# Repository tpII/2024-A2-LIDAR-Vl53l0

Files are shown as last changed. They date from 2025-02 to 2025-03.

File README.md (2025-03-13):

<!-- Titulo del proyecto -->

# A2-LIDAR-VL53L0X - CYCLOPS

<!-- Logo -->
<div align="center">
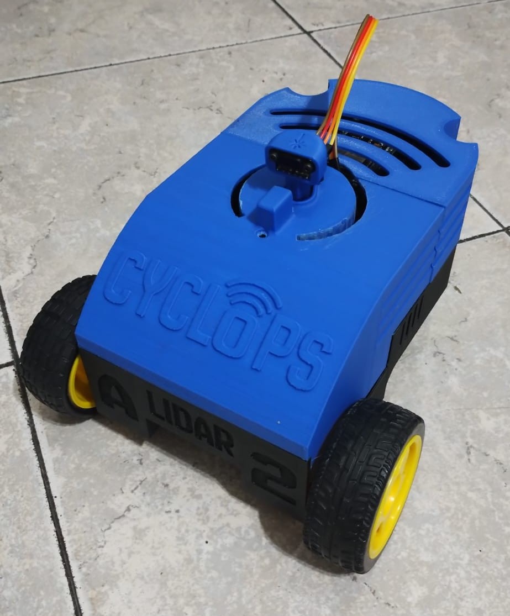
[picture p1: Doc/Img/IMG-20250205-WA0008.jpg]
  
</div>

<!-- Descripción del proyecto -->

Originalme **A2-LIDAR-VL53L0X, apodado Cyclops (en honor al héroe de Marvel)**, es un robot vehículo de 3 ruedas, de las cuales dos son motorizadas por motores DC, mientras que la tercera es una rueda loca que permite maniobras ágiles de desplazamiento.

El proyecto se destaca por el uso de un sensor **LiDAR VL53L0X montado sobre un servomotor de giro continuo**, lo que le permite al robot **detectar obstáculos** en su entorno en un radio de **300 grados**. La **MCU ESP32** gestiona todo el funcionamiento, comunicándose con el backend mediante HTTP y MQTT para recibir instrucciones y enviar datos como el nivel de batería, información del sistema y detalles de los obstáculos detectados, respectivamente.

El **backend**, desarrollado en **Maven con SpringBoot junto al broker Mosquitto**, almacena los datos para que puedan ser consultados tanto por el frontend como por el MCU. La base de datos utilizada es **MongoDB**.

El **frontend** está implementado con **Angular 18**, ofreciendo una **interfaz web** que permite **controlar el robot** mediante una serie de botones y con un mando conectado, además de **visualizar información** como el nivel de batería, mensajes de estado y un **mapa interactivo** que muestra los obstáculos detectados como **puntos en coordenadas <distancia, ángulo>.**

El objetivo principal de este proyecto fue desarrollar un **robot vehículo capaz de mapear su entorno y controlarlo** mediante una aplicación web de forma intuitiva y eficiente.

<details>
  <summary><i>:memo: Características del proyecto</i></summary>
  <ol>
    <li><b>Mapeo del Entorno<b></li>
    <p>Se puede decir que es la base del proyecto. Se realiza mediante la combinacion del sensor LiDAR VL53L0X que mide distancia, y un servomotor de giro continuo. Que mediante la logica adeacuada, scanea el entorno, obteniendo el par<distancia,angulo>. Que posteriormente se grafica en un mapa.</p>
    <li>Access Point</li>
    <p>El ESP32 actúa como punto de acceso (AP) para la conexión. De este modo la pc donde se ejectute el backend debe conectarse al la red del ESP32.</p>
    <li>Desarrollo Modular</li>
    <p>El programa está diseñado de manera modular, con componentes separados por funcionalidad, facilitando el mantenimiento y la extensión del proyecto.</p>
    <li>Replicabilidad</li>
    <p>El proyecto está documentado lo suficiente como para permitir replicar el control de un robot similar utilizando el hardware indicado.</p>
    <li>Extensibilidad</li>
    <p>Es posible ampliar el sistema para añadir mejoras de rendimiento o nuevas funcionalidades.</p>
  </ol>
    <li>Base educativa</li>
    <p>El proyecto es ideal para aprender acerca de programación de microcontroladores, conexiones hardware, utilizacion de sensores, integracion de Frontend<->Backend<->Hardware,sistemas concurrentes y de tiempo real, testeo y optimizacion de procesos.</p> </ol>
</details>

<details> 
  <summary><i>:satellite: Tecnologías utilizadas</i></summary>
  <ol> 
    <li>Aplicación web</li>
    <ul> 
      <li>Angular 18: framework frontend utilizado para la construcción de la interfaz de usuario, con un enfoque en componentes independientes y organización modular.</li>
      <li>Angular Material: utilizado para el diseño de la interfaz, proporcionando componentes estilizados y responsivos para una experiencia de usuario consistente.</li>
      <li>HTML, CSS y TypeScript: fundamentales para la estructura, estilo y lógica de la aplicación web, aprovechando las capacidades tipadas de TypeScript para un desarrollo más robusto.</li>
    </ul> 
    <li>Backend</li>
    <ul>
      <li>Java (Spring Boot): framework utilizado para construir el servidor backend, gestionando las solicitudes HTTP y la lógica de negocio.</li>
      <li>Maven: herramienta de gestión de dependencias y construcción del proyecto backend, asegurando un ciclo de desarrollo eficiente.</li>
      <li>MongoDB: base de datos NoSQL utilizada para almacenar la información persistente de la aplicación, con un enfoque en flexibilidad y escalabilidad.</li>
    </ul>
    <li>Comunicación en tiempo real</li>
    <ul>
      <li>Mosquitto Broker (MQTT): utilizado para la comunicación en tiempo real entre la aplicación web y el ESP32, permitiendo la transmisión de datos de forma eficiente y ligera.</li>
    </ul> 
    <li>ESP32</li>
    <ul>
      <li>Modo Soft AP: configurado como punto de acceso para permitir la conexión directa de dispositivos al ESP32.</li>
      <li>Programación en C: se utilizó para implementar la lógica de control del ESP32, incluyendo el manejo de sensores, motores y comunicación MQTT.</li>
      <li>PlatformIO: entorno de desarrollo integrado en Visual Studio Code para la programación y gestión del firmware del ESP32.</li>
      <li>DC Motors: utilizados para el movimiento del dispositivo, controlados mediante PWM para un desplazamiento preciso.</li>
      <li>Servo: utilizado para movimientos angulares específicos, controlado también mediante PWM.</li>
      <li>Sensores I2C: dos sensores conectados al ESP32 mediante el protocolo I2C para la recopilación de datos en tiempo real.</li>
    </ul>
  </ol>
</details>

<!-- Tabla de contenidos -->
<h1 id="table-of-contents">:book: Tabla de contenidos</h1>
<details open="open">
  <summary>Tabla de contenidos</summary>
  <ol>
    <li><a href="#prerequisites-software">➤ Prerequisitos-Software</a></li>
    <li><a href="#installation-esp32">➤ Instalación y Configuración del ESP32</a></li>
    <li><a href="#installation-mosquitto-broker">➤ Instalación y Configuración del Broker MQTT</a></li>
    <li><a href="#installation-backend">➤ Instalación y Configuración del Backend</a></li>
    <li><a href="#installation-mongodb">➤ Instalación y Configuración de MongoDB</a></li>
    <li><a href="#installation-frontend">➤ Instalación y Configuración del Frontend<</a></li>
    <li><a href="#execution-steps">➤ Pasos para la Ejecución del Proyecto</a></li>
    <li><a href="#video">➤ Video demostrativo</a></li>
    <li><a href="#bitacora">➤ Bitácora</a></li>
    <li><a href="#authors">➤ Autores</a></li>
    <li><a href="#coordinador">➤ Coordinador</a></li>
  </ol>
</details>

<!-- Prerequisitos SOFTWARE -->
<h1 id="prerequisites-software">🛠️ Prerequisitos-Software</h1>
<details>
  <summary>Prerequisitos-Software</summary>
  <p>El proyecto requiere la instalación de los siguientes componentes de software:</p>
  <ul>
    <li>
      <b>Visual Studio Code:</b> Editor de código necesario para el desarrollo tanto del frontend y backend, como del firmware para el ESP32.
    </li>
    <li>
      <b>PlatformIO:</b> Extensión de Visual Studio Code utilizada para compilar y cargar el firmware en el ESP32.
    </li>
    <li>
      <b>Java:</b> Requerido para ejecutar el backend en Spring Boot.
    </li>
    <li>
      <b>Maven:</b> Herramienta de gestión de dependencias y construcción para el backend en Spring Boot.
    </li>
    <li>
      <b>Node.js:</b> Necesario para Angular, incluyendo el uso de npm para la instalación de dependencias.
    </li>
    <li>
      <b>MongoDB:</b> Base de datos NoSQL utilizada para el almacenamiento de datos de la aplicación.
    </li>
    <li>
      <b>Broker Mosquitto:</b> Servidor MQTT utilizado para la comunicación en tiempo real con el ESP32.
    </li>
  </ul>
</details>

---

<!-- Prerequisitos ESP32 -->
<h1 id="installation-esp32">🛠️ Instalación y Configuración del ESP32</h1>
<details>
  <summary>Instalación y Configuración del ESP32</summary>
  <ol>
    <li>Abre <b>Visual Studio Code</b> y navega a la carpeta del proyecto: <code>2024-A2-LIDAR-VL53L0X</code>.</li>
    <li>Posiciónate en la carpeta <code>Microcontroller</code> (donde se encuentra el código en C).</li>
    <li>Conecta el ESP32 a un puerto USB de la computadora.</li>
    <li>Abrir <b>platformion.ini</b> y modificar <b>upload_port</b> con el numero de puerto al que se conecto el ESP32.</li>
    <li>Desde el menú inferior de <b>PlatformIO</b>, presiona el botón de subida de programa para compilar y cargar el firmware al ESP32.</li>
    <li>O en la consola, ejecutar <b>pio run -t upload<b></li>
  </ol>
  <p>Tras estos pasos, el ESP32 estará configurado y listo para ejecutar las instrucciones del proyecto.</p>
</details>

---

<!-- Prerequisitos BROKER MQTT-->
<h1 id="installation-mosquitto-broker">🕸️ Instalación y Configuración del Broker MQTT</h1>
<details>
  <summary>Instalación y Configuración del Broker Mosquitto</summary>
  <ol>
    <li>Descarga el instalador de Mosquitto MQTT Broker desde el sitio oficial de Eclipse Mosquitto: <a href="https://mosquitto.org/download/">https://mosquitto.org/download/</a>.</li>
    <li>Ejecuta el instalador y sigue las instrucciones para completar la instalación.</li>
    <li>Dirígete a la carpeta de instalación. Por defecto, se encuentra en:
      <pre><code>C:\Program Files\mosquitto</code></pre>
    </li>
    <li>Configura el Broker editando el archivo <code>mosquitto.conf</code> con un editor de texto (ej. Notepad++ o Visual Studio Code). Añade las siguientes líneas para permitir conexiones anónimas y habilitar la salida de eventos por consola:
      <pre><code>
listener 1883
allow_anonymous true
log_type all
connection_messages true
log_timestamp true
      </code></pre>
    </li>
    <li>Guarda los cambios en el archivo de configuración.</li>
    <li>Abre una consola en modo administrador y navega hasta la carpeta de instalación:
      <pre><code>cd "C:\Program Files\mosquitto"</code></pre>
    </li>
    <li>Inicia el Broker Mosquitto utilizando el siguiente comando:
      <pre><code>mosquitto -v -c mosquitto.conf</code></pre>
      <p>Este comando inicia el Broker en modo verbose, mostrando todos los eventos y conexiones en tiempo real en la consola.</p>
    </li>
    <li>El Broker MQTT ahora debería estar en funcionamiento y listo para gestionar las conexiones.</li>
  </ol>
</details>

---

<!-- Prerequisitos BACKEND -->
<h1 id="installation-backend">🔧 Instalación y Configuración del Backend</h1>
<details>
  <summary>Instalación y Configuración del Servidor Backend</summary>
  <ol>
    <li>Abre Visual Studio Code y clona el repositorio.</li>
    <li>Posicionate en la carpeta del repositorio: <code>2024-A2-LIDAR-VL53L0X</code>.</li>
    <li>Accede a la carpeta del backend con el siguiente comando:</li>
    <pre><code>cd backend</code></pre>
    <li>En la consola, ejecuta el siguiente comando para instalar las dependencias del proyecto:</li>
    <pre><code>mvn clean install</code></pre>
    <li>Para levantar el servidor, ejecuta el siguiente comando:</li>
    <pre><code>mvn spring-boot:run</code></pre>
    <li>El servidor se iniciará y quedará a la espera de conectarse a la red del ESP32.</li>
  </ol>
  <p>El backend estará listo para funcionar con el ESP32.</p>
</details>

---

<!-- Prerequisitos MongoDB -->
<h1 id="installation-mongodb">📦 Instalación y Configuración de MongoDB</h1>
<details>
  <summary>Instalación de MongoDB</summary>
  <ol>
    <li>Descarga e instala MongoDB desde el instalador oficial.</li>
    <li>No es necesaria ninguna configuración adicional, solo asegúrate de habilitar la ejecución en segundo plano.</li>
    <li>El backend se conectará automáticamente a MongoDB al levantarse el servidor.</li>
  </ol>
  <p>MongoDB estará listo para almacenar los datos del proyecto.</p>
</details>

---

<!-- Prerequisitos FRONTEND -->
<h1 id="installation-frontend">🌐 Instalación y Configuración del Frontend</h1>
<details>
  <summary>Instalación y Configuración del Servidor Frontend</summary>
  <ol>
    <li>Abre Visual Studio Code y clona el repositorio.</li>
    <li>Posicionate en la carpeta del repositorio: <code>2024-A2-LIDAR-VL53L0X</code>.</li>
    <li>Accede a la carpeta del frontend con el siguiente comando:</li>
    <pre><code>cd Frontend</code></pre>
    <li>En la consola, ejecuta el siguiente comando para instalar las dependencias del proyecto:</li>
    <pre><code>npm install</code></pre>
    <li>Verifica la correcta instalación de Angular ejecutando el siguiente comando:</li>
    <pre><code>ng version</code></pre>
    <li>Para levantar el servidor, ejecuta el siguiente comando:</li>
    <pre><code>ng serve</code></pre>
    <li>La página estará accesible en el siguiente enlace: <a href="http://localhost:4200">http://localhost:4200</a>.</li>
  </ol>
  <p>El frontend estará listo para interactuar con el backend y el ESP32.</p>
</details>

---

<!-- video explicativo-->
<h1 id="video">:clapper: Video del Proyecto </h1>
<p>A continuacion se deja un link, a un video explicativo sobre el robot y su funcionamiento: <a href="https://drive.google.com/file/d/1UwNFf568G4iCPq6gYDLypO1Pdrs1-ocO/view?usp=drive_link">Video</a></p>

<h1 id="bitacora">:bookmark_tabs: Bitácora</h1>

<p>Como parte del proyecto se redacto una bitacora con el "dia a dia" del mismo: <a href="https://github.com/tpII/2024-A4-QLEARNING-ESP32/wiki/Bitacora-A4-%E2%80%90-Crawler-Robot-con-ESP32)">Bitacora</a>.</p>

<h1 id="authors">✒️ Autores</h1>

| Autor | GitHub |
| --- | --- |
| **Guerrico Leonel** |  |
| **Octavio Perez Balcedo** |  |
| **Ossola Florencia** |  |

---

<h1 id="coordinador">📌 Coordinador</h1>

| Coordinador | GitHub |
| --- | --- |
| **Alan Fabián Castelli** _Profesor - Ayudante_ |  |

<!-- Licencia -->
<h1 id="license">📄 Licencia</h1>
<details>
  <summary>Licencia</summary>
  <p>Este proyecto está bajo la Licencia <b>GPL-3.0 license</b>.</p>
  <p>Mira el archivo <code>LICENSE</code> para más detalles.</p>
</details>

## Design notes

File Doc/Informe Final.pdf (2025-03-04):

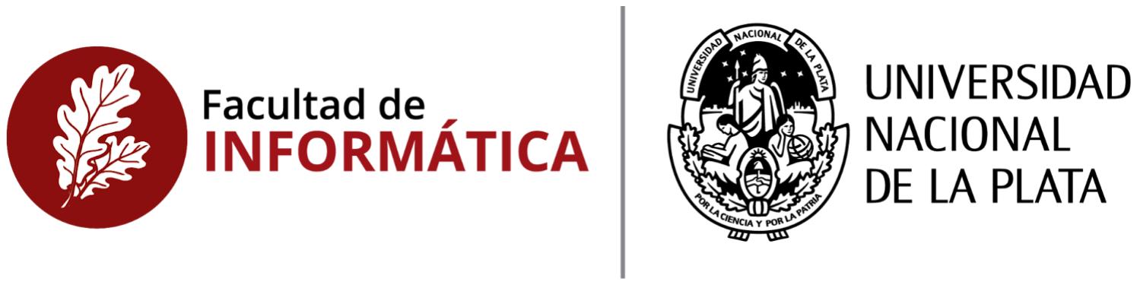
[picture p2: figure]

Taller de Proyecto 2
Informe Final

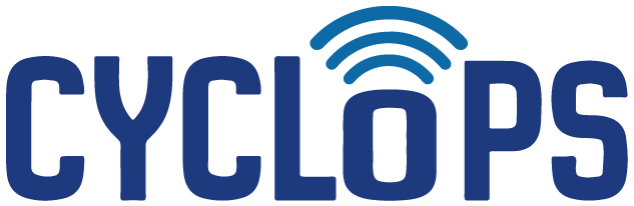
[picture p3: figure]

### A2 - Armado de robot mapeador con sensor LIDAR Vl53l0

Guerrico Leonel - 02009/5

Ossola Florencia - 02226/2

Pérez Balcedo Octavio - 02236/4

### 7 de Febrero de 2025

### Índice

Índice | 2
1.1 Introducción | 3
1.2 Objetivos y Propuesta | 4
1.3 Correcciones Realizadas | 5
2 Proyecto | 8
2.1 Grafico Procesos y Funciones | 8
2.2 Esquemático de Conexiones del Hardware | 15
2.3 Estado alcanzado en la funcionalidad | 17
3 Documentación del Software | 18
3.1 Pre-requisitos | 18
3.2 Librerías del ESP32 | 22
3.2.2 Mapping | 24
4 Documentación Relacionada | 37
4.1 Interfaz Web | 37
4.2 Hardware | 39
4.3 Manual de Usuario | 41
4.4 Enlaces | 42
5 Conclusión | 43
5.1 Mejoras | 43
6 Bibliografía | 45
7 Apéndice A: Materiales y Presupuesto | 46

### 1.1 Introducción

Al ingresar a la materia se nos presentaron unas series de posibles proyectos a realizar, y tras analizarlos decidimos elegir el conocido como proyecto - A.2 Armado de sensor LIDAR[1] con Vl53l0-, y al que, para simplificar, apodamos Cyclops, en referencia al héroe de Marvel.
El mismo nos presentaba el desafío de diseñar un vehículo a control remoto el cual contará con la capacidad de detectar los obstáculos de su entorno mediante la utilización de tecnología Lidar; y a partir de esto generar un mapa donde se visualizan dichos obstáculos. Además, se nos planteó la utilización del chip ESP32[2] como el microcontrolador a cargo de todo el sistema.
En tanto que para el control del vehículo y para visualizar dicha información, se nos solicitó implementar una aplicación web.

Este proyecto está inspirado en los robots y drones que se utilizan normalmente para el mapeo de entornos con tecnología LiDAR, y en particular en el proyecto Linorobot del usuario Rud Merriam [3]. El cual es un robot de pequeñas dimensiones equipado con un LiDAR de alta capacidad, el cual realiza un mapa de su entorno utilizando ROS[4].

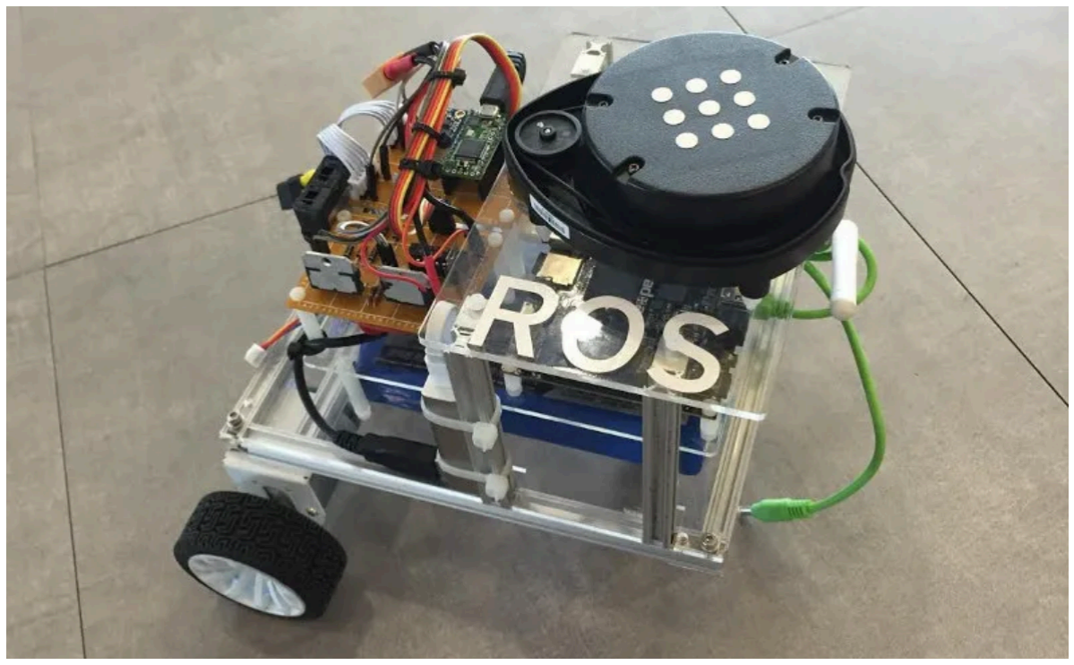
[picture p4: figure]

Imagen 1: Linorobot de Rud Merriam (fuente:hackaday.com (https://hackaday.com/2016/03/13/petite-package-provides-powerful-robot/) )

### 1.2 Objetivos y Propuesta

Como se comentó anteriormente, el objetivo principal de este proyecto fue desarrollar un robot que se maneja a control remoto, y que mapee su entorno mediante un sensor LiDAR, y una app web como complemento para visualizar los datos provenientes del mismo, así como facilitar su manejo.

Por tanto el proyecto se subdividió de la siguiente manera:

### 1.2.1 Objetivos Primarios

Se propuso como objetivo primario el diseño e implementación de un vehículo a control remoto, el cual utilizara un mcu ESP32 como centro del sistema, y un LiDAR VL53L0X[5] como sensor para el mapeo. Además de una aplicación web para centralizar el manejo del mismo, y visualización de los datos; y por otro lado, el diseño físico del mismo, pensándolo para ser impreso en 3D.
A partir de esto se esquematizan los siguientes funcionalidades principales:
1. Mapeo 2D completo de un área determinada: Implementar el algoritmo y diseño de hardware necesario para que el robot realice un mapeo del área utilizando el sensor LiDAR para detectar obstáculos en el mismo.
2. Medición de distancia: Implementar el algoritmo correspondiente para que el robot realice el cálculo necesario para obtener la distancia entre él y los obstáculos durante el mapeo.
3. Desplazamiento de vehículo: El robot debe poder desplazarse hacia adelante, atrás o doblar según el usuario lo desee en el área en la que se encuentra.
4. Comunicación entre el cliente y el robot: El robot debe ser capaz de responder a las órdenes del usuario, estas pueden ser con respecto al desplazamiento, pausa, entre otras.
5. Visualización de datos mediante una interfaz: Desarrollar una página web donde el usuario podrá visualizar los datos relacionados al mapeo y mensajes importantes del sistema.
6. Montaje de Hardware: Realizar el diseño del robot y montaje de los componentes necesarios para su funcionamiento.

a. Comunicación entre el microcontrolador y los motores.
b. Comunicación entre el microcontrolador y el servomotor.
c. El servomotor debe controlar el movimiento del sensor LiDAR.

### 1.2.2 Objetivos Secundarios

Además de los objetivos principales, se propusieron una serie de objetivos secundarios para complementar el sistema, los cuales no eran prioritarios. Estos eran:

1. Incorporar baterías para el funcionamiento independiente del vehículo.
2. Incorporar al hardware un INA219[6] para la medición de carga de las baterías, y la lógica para informar de dichos valores al usuario.
3. Diseñar un software para el manejo autónomo del vehículo, es decir, que el vehículo funcione sin necesidad de controlarlo, en base a detectar caminos viables entre los obstáculos.

### 1.3 Correcciones Realizadas

### 1.3.1 Protocolos de Comunicación ESP32 - Servidor

Originalmente se implementó HTTP[7] como protocolo de comunicación entre el ESP32 y el Servidor(notebook), no obstante, tras un análisis, se determinó que este protocolo no era conveniente para una comunicación rápida y eficiente, pues no era óptimo para IOT[8], por tanto se lo reemplazó con MQTT[9]. Dicho protocolo nos permite mantener conexiones activas de forma permanente (salvo desconección), lo que facilita el envío rápido de múltiples datos desde el ESP32 al servidor.
No obstante, posteriormente debido a un problema con MQTT que no se logró solucionar, se volvió a implementar HTTP nuevamente, aunque solo para el envío de instrucciones al ESP32.

### 1.3.2 Servomotor de giro continuo

Inicialmente se trabajó bajo la idea errónea, de que el servomotor dado, funcionaba de forma similar al servomotor típico sg90[10], lo que implicó el diseño de hardware e implementación de una librería no funcionales.
Posteriormente, tras analizar el servomotor, y entender que él mismo era de giro continuo, se rediseñó todo el sistema, ya que dichos servomotores, no proveen información alguna, solo giran en el sentido indicado.
Esto implicó un rediseño completo de la lógica y hardware, pues ahora se debió incluir un sensor de fin de carrera, de tal modo que al ser presionado por el servomotor, se genere a nivel software un valor de referencia, a partir del cual se implementa todo el comportamiento, como la inversión del sentido, cálculo de ángulo, y demás.

### 1.3.3 Sensor INA219

Como parte de los objetivos secundarios se propuso la inclusión de un sensor INA219, para el sensado del nivel de batería, lo que se tuvo en cuenta desde un primer momento en el diseño del circuito. No obstante, por una mala lectura de la documentación, se colocó el sensor en paralelo a la carga, cuando se debe conectar en serie, pues mide la corriente y no la tensión.
Debido a esto, se tuvo que corregir el circuito, para poder utilizarlo correctamente.

### 1.3.4 I2C

Como parte central del proyecto se diseñó un circuito pensándolo para implementarlo como un PCB de una capa, el cual se llevó a cabo, de cara al ensamblado final del vehículo..
Inicialmente el mismo pareció funcionar correctamente, hasta el momento de testear los sensores, momento en el cual ninguno de los dos(INA219 y LiDAR VL53L0X) respondía. Tras múltiples testeos y análisis, se llegó a la conclusión de que el diseño estaba mal, y que no se consideró como el ruido afectará a las pistas I2C[11], así como se debían ubicar las mismas, para que no se vieran afectadas por las demás. Esto implicó el rediseño completo del circuito, y el descarte del PCB[12] hecho.

### 1.3.4 Memory Leak

Durante la etapa de pruebas para dejar funcionando el robot, se detectó memory leak, lo cual provocaba el crasheo del sistema en el ESP32. Para solucionar esto se realizaron pruebas exhaustivas para detectar el origen del leak, y solucionarlo. Dando como resultado::
- Manejo de JSON: como formato a la hora de la comunicación, se utiliza el formato JSON. Y para utilizarlo en el ESP32 se optó por la librería cJSON, una de las más extendidas y prácticas de utilizar. No obstante, al testear se encontró que era extremadamente ineficiente en el uso de memoria, dado que esta utiliza internamente listas enlazadas, una estructura de datos altamente demandante de memoria. Razón por la cual se la reemplazó por frozen, (https://github.com/cesanta/frozen) la cual es mucho más eficiente, por ejemplo: haciendo el envío de datos 10 veces más rápido.
- Manejo de Punteros: como parte de muchas funcionalidades se debió utilizar punteros, algunos de los cuales al no manejarse adecuadamente, en concreto, liberarse; al cabo de un minutos ejecutando, colapsaban la memoria.

### 1.3.5 Conexión Backend Broker

Uno de los problemas que tuvimos al preparar la presentación, fue la conexión del Backend a MQTT, especialmente en la notebook para la demostración del proyecto, algo que sucedía en otra de las computadoras. Tras sucesivas pruebas, resultó que http//localhost:8080 no funcionaba, y que al reemplazar localhost por la IP que le asigna el ESP32 al servidor, esto se solucionaba.
Cabe aclarar que dicha IP al ser único dispositivo que se conecta al ESP32, es siempre la misma, por lo que es seguro hacerlo de esta forma.

## 2 Proyecto

### 2.1 Grafico Procesos y Funciones

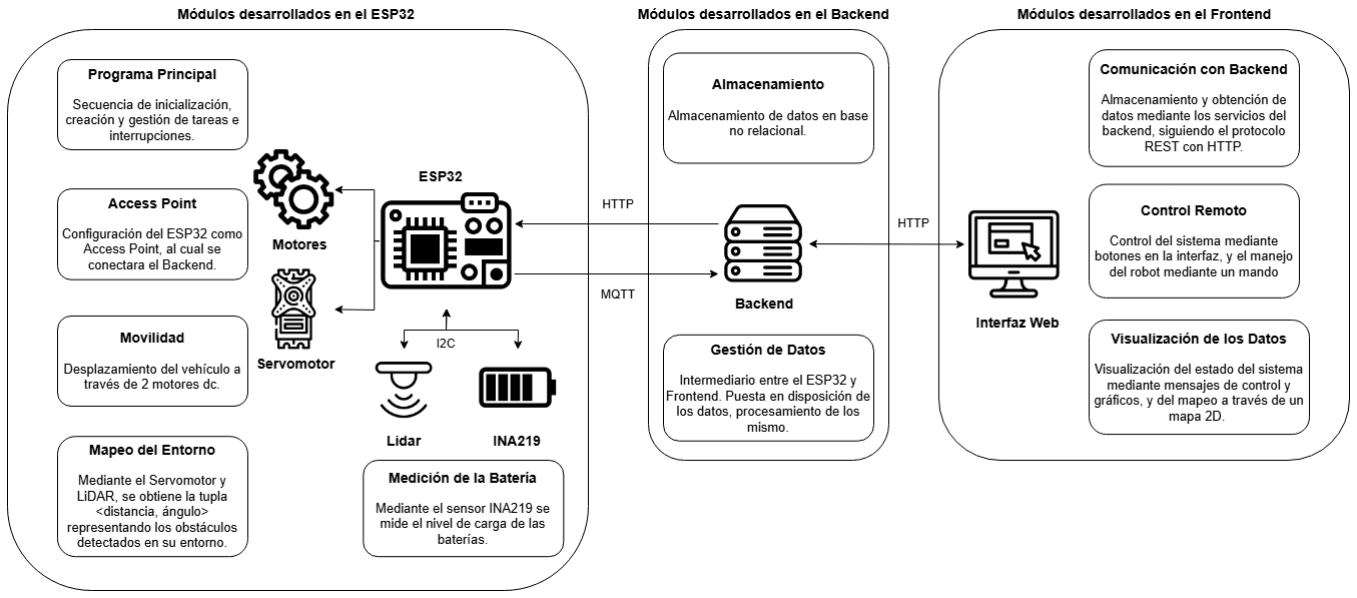
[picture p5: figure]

Figura 1: Esquema Completo del Sistema

Para visualizar las funciones y procesos que posee el código fuente del robot, se realizó un esquema del sistema que permita rápidamente entender cada una de las funciones en el mismo. (Figura 1). Para una mejor vista se adjunta este diagrama en el Anexo.
La mayoría de las funciones y procesos fueron desarrolladas por el equipo de trabajo, no obstante dos librerías fueron adaptadas de librerías públicas en github[13]. Dichas librerías son las que permiten comunicarse mediante I2C con los sensores, i2c_vl53l0x para el LiDAR, basada en el codigo de Artful Bytes[29], y de igual manera la ina219v2 basadas en el código de Ruslan V. Uss. (https://github.com/UncleRus/esp-idf-lib/blob/master/components/ina219/ina219.c) Esto, ya que el manejo de los sensores es altamente complejo (principalmente respecto al LiDAR) debido al manejo de los registros. Razón por la cual, se optó por la utilización de código ya probado y funcional.

### 2.1.2 Funciones de Cyclops

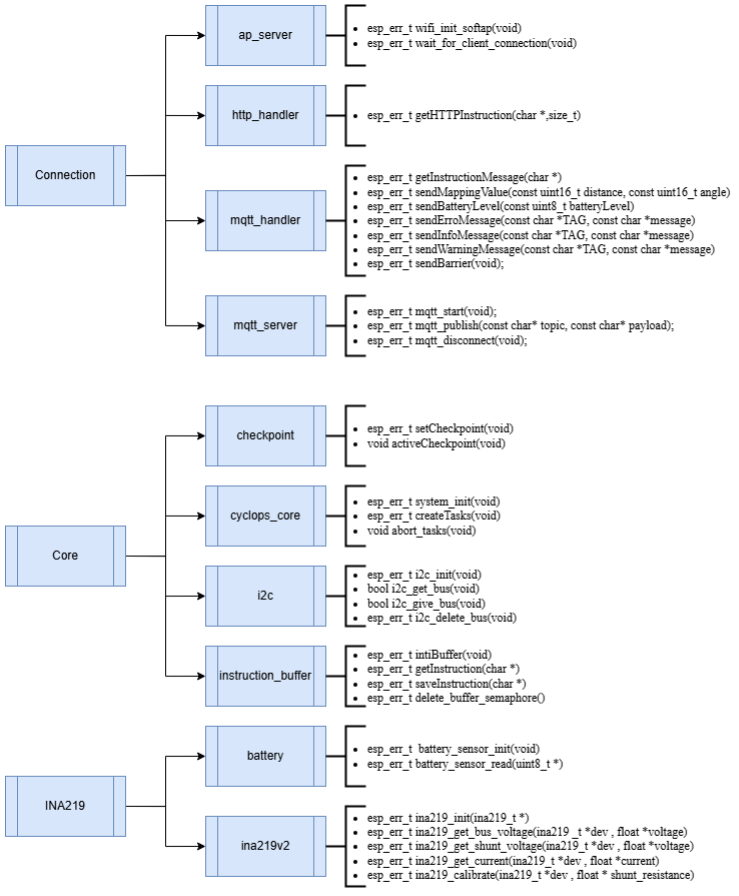
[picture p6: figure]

Figura 2: Parte 1 - Funciones del Robot

La Figura 2, representa una parte de las funciones del robot, englobadas en sus librerías y estas en grupos según a la tarea con la que se relacionaban. Por ejemplo, ap_server, http_handler, mqtt_handler y mqtt_server, comprenden la lógica necesaria para comunicar el ESP32 con el Backend, por tanto se agrupan en la carpeta Connection.

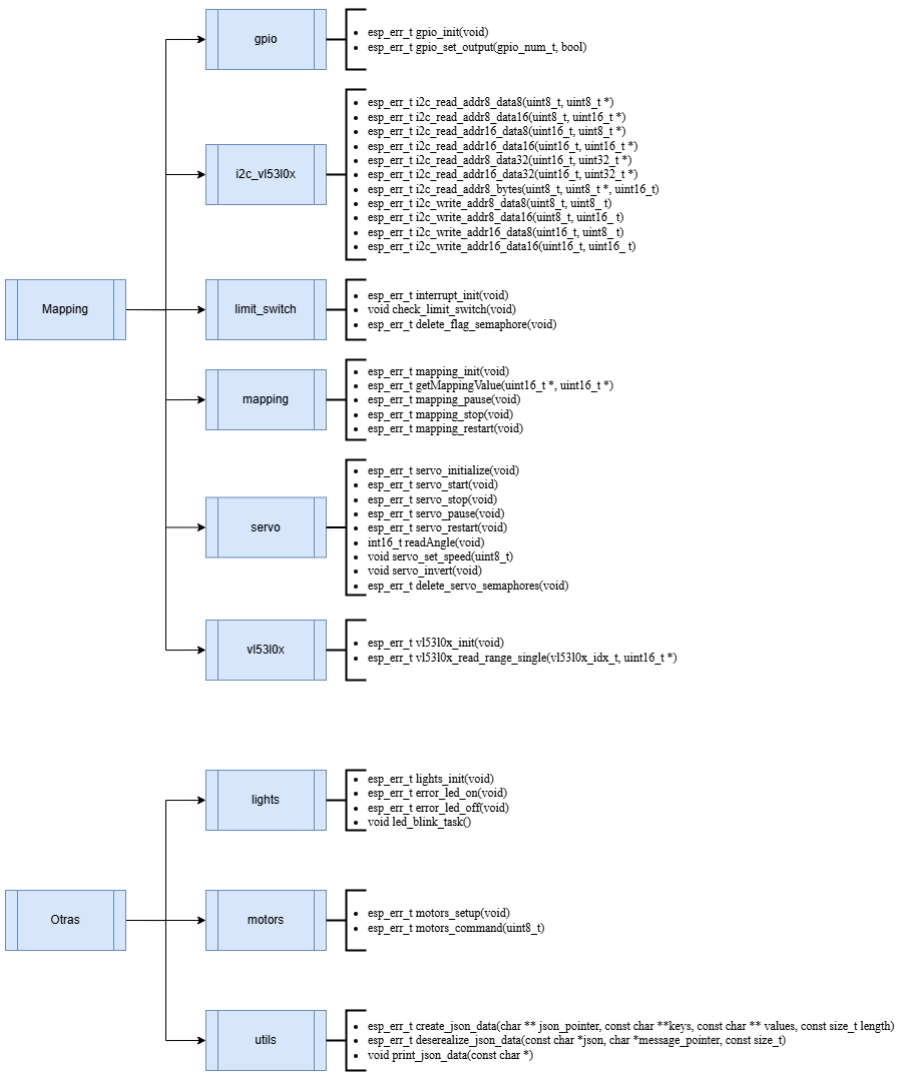
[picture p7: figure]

Figura 3: Parte 2 - Funciones del Robot

En esta última figura, se ilustran los demás grupos de librerías, en particular Mapping, la cual comprende las librerías necesarias para llevar a cabo el mapeo del entorno. Función que requirió de una lógica extensiva, que incluye el manejo del servomotor, el manejo del LiDAR junto con su comunicación I2C, y el sensor de carrera antes mencionado.

### 2.1.3 Diagrama de Flujo

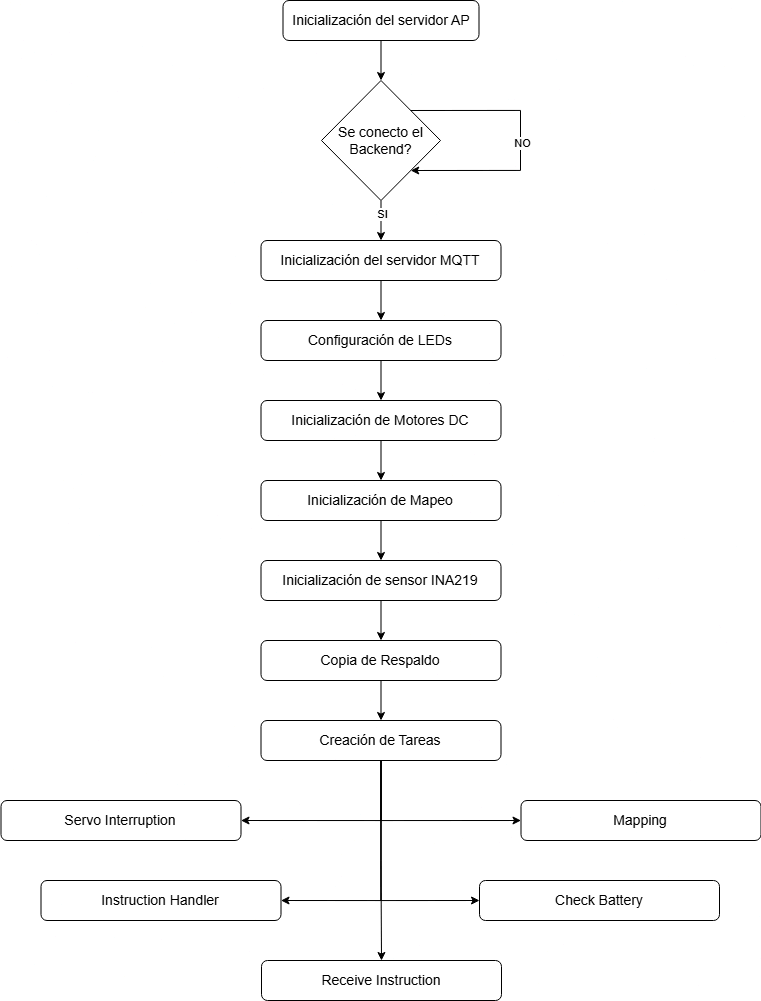
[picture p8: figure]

Figura 4: Diagrama de flujo General

Esta figura representa el diagrama de flujo general del programa principal. En específico la cadena de inicialización del sistema, finalizando con la creación de la tareas, que llevarán a cabo las funciones principales del sistema, las cuales se detallan a continuación.

### 2.1.3.1 Servo Interruption

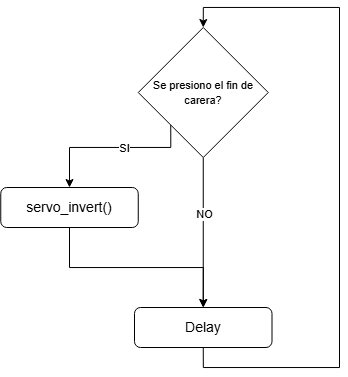
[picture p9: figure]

Figura 5: Diagrama de flujo de la tarea Servo Interruption

Esta tarea, como se ve en el diagrama se basa en accionar la función servo_invert() siempre que se presione el fin de carrera; esto de forma periódica mediante un delay.
La función servo_invert(), se encarga de invertir el sentido de giro del servomotor, y establecer el tiempo de referencia, entre otras cosas.

### 2.1.3.2 Instruction Handler

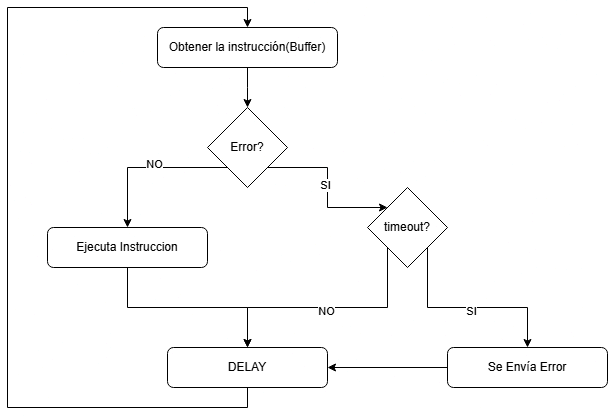
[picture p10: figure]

Figura 6: Diagrama de flujo de la tarea Instruction Handler

Esta tarea se encarga de obtener la instrucciones a ejecutar del buffer de instrucciones. Si la obtiene, ejecuta la mismas, sino, analiza si el error fue por timeout, lo que indicaría que hubo un problema considerable al intentar obtenerla, por lo que se envía el error al usuario. En cualquier otro caso, se ejecuta un delay, se vuelve a iniciar el bucle.

### 2.1.3.3 Receive Instruction

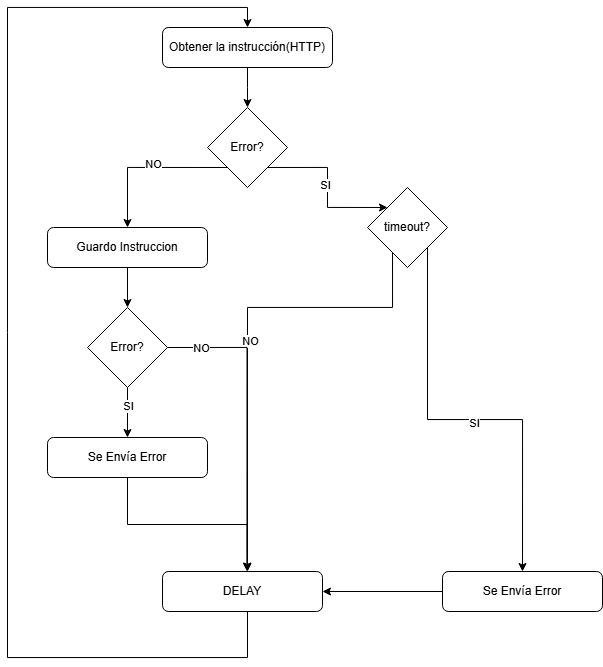
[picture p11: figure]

Figura 7: Diagrama de flujo de la tarea Receive Instruction

Esta tarea comienza realizando un get HTTP al backend para obtener la siguiente instrucción, y si la consulta resulta exitosa, es decir, se obtuvo una instrucción, se guarda en el buffer de instrucciones. En caso de fallar la función, y devolver un error por timeout, se envía el error al usuario, si no, continúa el bucle ejecutando el delay.
Si al guardar la instrucción ocurre un error, sucede lo mismo, se envía el error al usuario, y se continua el bucle.

### 2.1.3.4 Check Battery

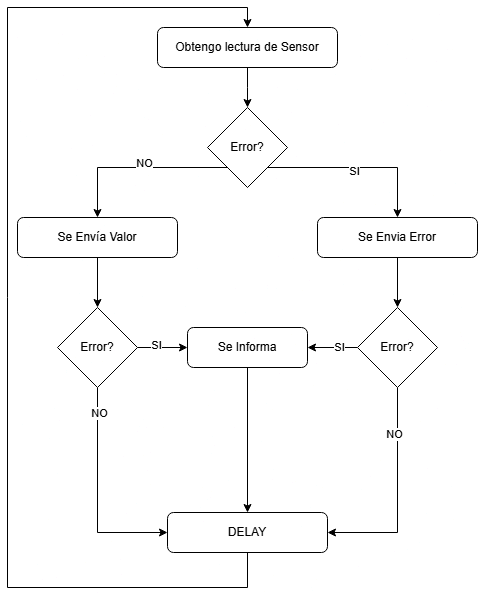
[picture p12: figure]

Figura 8: Diagrama de flujo de la tarea Check Battery

Esta tarea se encarga de obtener periódicamente el valor de carga de la batería y enviarlo al backend. En caso de no poder obtenerlo, se envía el error al usuario. No obstante, tanto el envío del error, como del valor, pueden fallar, en este caso, se informa por conexión serie, pues falla la comunicación.

### 2.1.3.5 Mapping

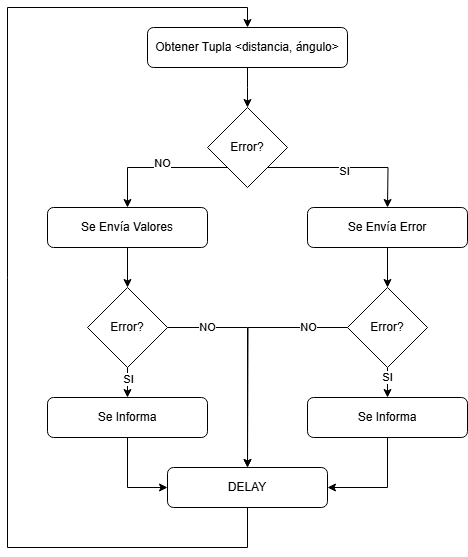
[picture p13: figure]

Figura 9: Diagrama de flujo de la tarea Check Battery

Esta tarea compone la función principal del vehículo, la cual es el mapeo de su entorno. Comienza al tratar de obtener la tupla <distancia, ángulo>, y si se obtiene, se envía el valor; en caso contrario se envía el error. A su vez, si se produce un error en alguno de los envíos, se informa de ello mediante conexión serie. Y posteriormente, indiferentemente del caso, se continúa el bucle.

Como se puede apreciar en los distintos diagramas, no se entró en detalle en cómo se realizan las distintas operaciones, ya que se explicará más detalladamente en secciones posteriores. Otro punto a destacar es que cuando el envío de errores, o “valores” falla, se informa de esto mediante conexión serie, algo que requiere tener conectado el ESP32 a un PC, lo que no corresponde al funcionamiento normal. Esto se debe a que estos fallos no deberían ocurrir, ya que serían resultado de comportamientos anormales, y evidentes por sí mismos, al no llegar los “valores” al usuario, y en este punto sería necesario conectarlo al pc para ver qué sucede.

### 2.2 Esquemático de Conexiones del Hardware

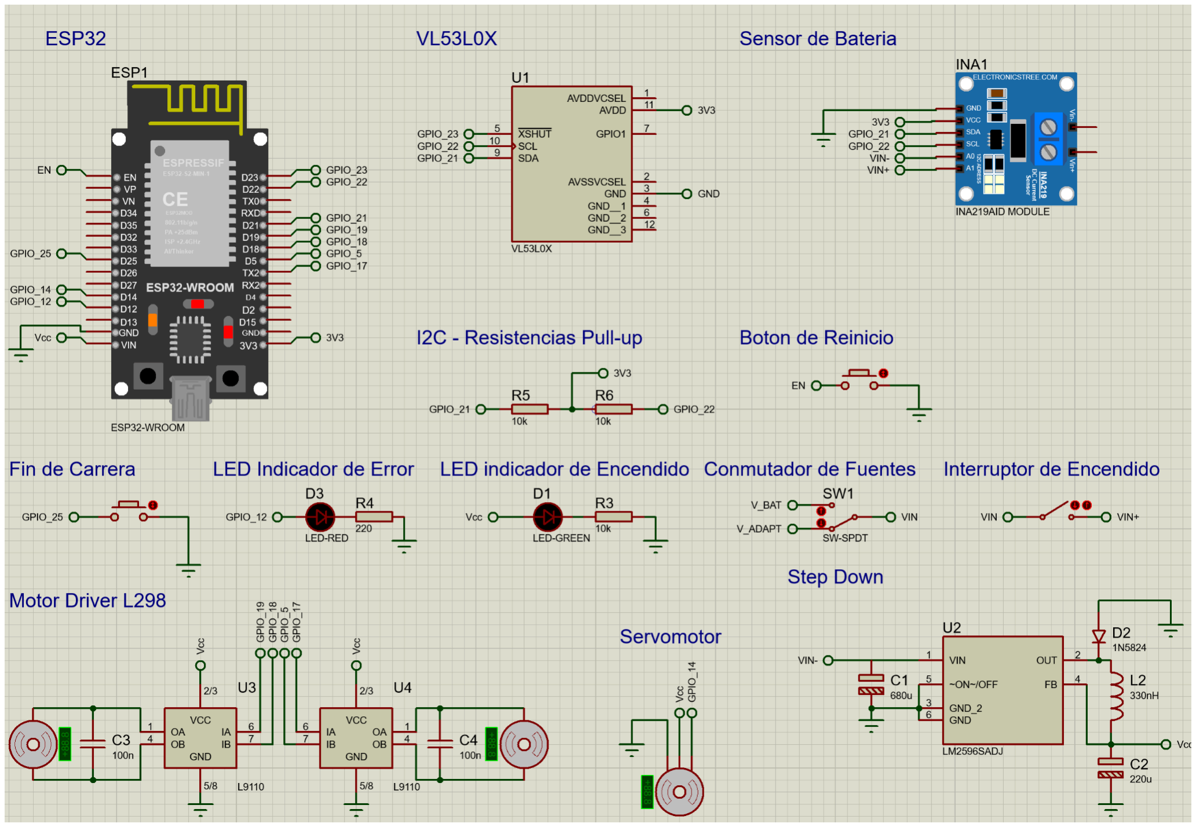
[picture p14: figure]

Figura 10: Esquema de Conexiones

La figura anterior es una captura del Esquemático realizado en Proteus[14], en el cual se pueden apreciar las distintas conexiones del circuito del robot. Principalmente el ESP32, el Servomotor, y INA219, siendo los más voluminosos. Aunque también se encuentran el LiDAR VL53L0X del cual no encontró una versión “más visual”, colocando un versión técnica, junto con el Motor Driver (con los 2 motores) y el step down, de los cuales no se encontró integrados. En el caso del driver, se lo representó por los 2 puentes H, mas no es el circuito completo, y en el caso del step down se armó una aproximación del circuito del integrado siguiendo la datasheet.
Por otro lado, también se puede apreciar conexiones adicionales, como las resistencias pull-up para las conexiones I2C de los sensores, los dos leds indicadores, el fin de carrera, y los botones de reinicio, encendido y apagado, junto con el conmutador, el cual nos permite optar entre la fuente de alimentación y las baterías. En este último punto, debemos aclarar que el robot, cuenta con dos fuentes de energía, una fuente de alimentación que convierte la corriente de 220V a 9V provista por la cátedra, y dos pilas 18650[15], que proveen la energía para que el robot opere independientemente a distancia, sin estar conectado a la red eléctrica.
En ambos casos, la tensión protista será bajada a 5V por el step-down, pues es el voltaje máximo utilizado por la mayoría de componentes. En el caso del LiDAR y el INA219 que funcionan con 3.3V, se alimentan del ESP32, el cual funcionará además, como convertidor de 5V a 3.3V.

### 2.3 Estado alcanzado en la funcionalidad

En la siguiente tabla se podrá observar un listado de las funciones propuestas en el comienzo del proyecto indicando el estado alcanzado al momento de finalizar el proyecto.

Funcionalidad | Requerimiento | Estado
Mapeo 2D completo del área | Implementar algoritmo para controlar el sensor LiDAR para realizar un mapeo del área. | TOTAL

Implementar algoritmo para controlar el servomotor y manejar el movimiento del sensor LiDAR.
Comunicación con el backend para almacenar los valores.
Implementar algoritmo que calcule la distancia entre el robot y el obstáculo detectado.
Desplazamiento del vehículo | El robot debe ser capaz de desplazarse hacia adelante, atrás, girar y frenar según el usuario se lo indique. | TOTAL
Comunicación entre el usuario y el robot | El usuario debe ser capaz de enviarle instrucciones al robot.

El robot debe ser capaz de ejecutar la instrucción recibida.
Diseño e implementación de la página web. Visualización de los datos en la interfaz web. Backend como intermediario.

Montaje de hardware

Diseño del robot.

TOTAL

Montaje de los componentes.
El MCU debe poder comunicarse correctamente con los otros componentes (motores, servo, sensores).
El servomotor debe estar posicionado para poder controlar el movimiento del sensor LiDAR.

Medición de batería

Incorporar baterías en el diseño. Incorporar el sensor INA219 en el diseño.

| Implementar algoritmo para la lectura y medición de carga.
Manejo autónomo del vehículo | Implementar algoritmo para que el vehículo sea capaz de desplazarse sin necesidad de controlarlo. | SIN REALIZAR

Detectar caminos viables entre los obstáculos.
Testeo | Realizar una fase de testeos para comprobar el funcionamiento del sistema. | PARCIAL
| Testeo de la interfaz.
| Testeos de los componentes físicos.
| Testeo del mapeo

Tabla 1: Estado de las funciones propuestas.

Como se puede observar, hay 3 estados: TOTAL, PARCIAL y SIN REALIZAR. Estos se utilizan para indicar que tareas fueron completadas totalmente, cuales se iniciaron pero no se logró realizar un testeo más exhaustivo o agregar determinadas optimizaciones, y por último qué tareas no se pudieron comenzar por falta de tiempo o que luego de un análisis no resultaba conveniente desarrollarlas.

## 3 Documentación del Software

### 3.1 Pre-requisitos

El proyecto requiere de los siguientes componentes a nivel software para su ejecución:

- VScode (Visual Studio Code) [16]
- PlatformIO (extension para VScode) [17]
- Mosquitto MQTT Broker [18]
- MongoDB [19]
- Node [20]

Habiendo instalado los componentes, procedemos a explicar los pasos necesarios para montar el código del ESP32, levantar el server y el frontend.

### 3.1.1 MQTT Broker

El protocolo MQTT exige un broker, es decir, un gestor de la conexión entre los dispositivos. En nuestro caso utilizamos Mosquitto, un broker de Open Source[21] de Fundación Eclipse[22].

0. Instalar Mosquitto MQTT Broker con el instalador descargado.

### 1. Abrir la carpeta donde se instaló, en nuestro caso “C:\Program Files\mosquitto” 2. Configurar el Broker modificando el archivo .conf para admitir conexiones sin

credenciales y anónimas, y la salida por consola de eventos, mediantes las siguientes líneas:
listener 1883
allow_anonymous true
log_type all
connection_messages true
log_timestamp true

### 3. Abrir consola en modo administrador y ubicarse en la carpeta de instalación del

Broker

### 4. Ejecutar el broker mediante el comando mosquitto -v -c mosquitto.conf

De este modo el broker quedará configurado y ejecutándose, además se podrá visualizar el flujo de mensajes en la consola.

### 3.1.2 ESP32

Para desarrollar el código del ESP32 se utilizó el framework del fabricante Expressif, IDF
[23] en la versión 5.2.2 en lenguaje C, y como plataforma VScode con la extension PlatformIO version 3.16.

### 0. Abrir VScode, clonar el repositorio, y posicionarse en la carpeta del mismo:

2024-A2-LIDAR-VL53L0X
1. Posicionarse sobre la carpeta Microcontroller donde se encuentra el código. En la carpeta src se halla el main.c y lib, las distintas librerías.
2. En la consola ejecutar cd Microcontroller, para poder ejecutar comandos de PlatfomtIO.

### 3. Abrir platformio.ini, y modificar upload_port con el número de puerto asignado en tu

computadora.

4. Ejecutar pio run -t upload, para cargar el código al ESP32.
NOTA: no se debe estar conectado por monitor serie al ESP32 al momento de ejecutar.

De este modo se logra cargar el código al ESP32.
Debe mencionarse que se puede evitar ejecutar los comandos, utilizando la interfaz provista por PlatformIO.

Comandos extra:
- pio run: compila el código.
- pio run -t clean: limpia el proyecto.
- pio run -t erase: limpia el ESP32.

### 3.1.3 Backend

Para el backend se utilizó lenguaje Java con el JDK [24] versión 23, y los frameworks Maven [25] (versión 4.0) y Spring Boot [26] (versión 3.0).

### 0. Abrir VScode, clonar el repositorio, y posicionarse en la carpeta del mismo:

2024-A2-LIDAR-VL53L0X
1. Posicionarse sobre la carpeta Backend donde se encuentra el código.
2. En la consola ejecutar cd backend, para poder ejecutar comandos en el código.

### 3. Ejecutar mvn clean install para instalar todas las dependencias 4. Ejecutar mvn spring-boot:run para levantar el servidor

5. El servidor queda a la espera de conectarse a la red del ESP32.

Respecto a la base de datos, esta es una no relacional, en nuestro caso MongoDB. Para utilizarla se debe ejecutar el instalador descargado, sin necesidad de alguna configuración adicional, solo habilitar su ejecución en segundo plano. El backend se conectará de forma automática

### 3.1.4 Frontend

En el caso del Frontend habiendo instalado Node.js, ya no es necesario hacer ninguna otra modificación.

### 0. Abrir VScode, clonar el repositorio, y posicionarse en la carpeta del mismo:

2024-A2-LIDAR-VL53L0X
1. Posicionarse sobre la carpeta Frontend donde se encuentra el código.
2. En la consola ejecutar cd Frontend, para poder ejecutar comandos en el código.
3. Ejecutar npm install, para instalar las dependencias.
4. Ejecutar ng version para verificar la correcta instalación de Angular [27].
5. Ejecutar ng server.

Con esto hecho, la página ya es accesible en el link localhost:4200.

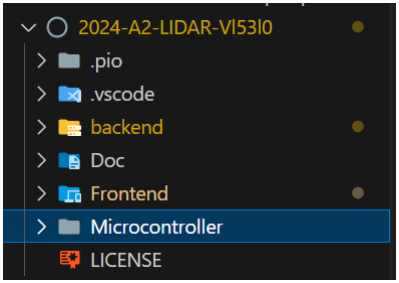
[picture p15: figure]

Figura 11: Carpeta del Proyecto

Como se mencionó anteriormente, se debe clonar el repositorio, al hacerlo, este se ve como en la imagen.

### 3.1.4 Hardware

Respecto al hardware, además de la PC para ejecutar el backend, base de datos y frontend, y del propio robot, solo se debe contar con un mando tipo consola, para poder controlar el vehículo, pues como se explicará más adelante, la interfaz web, cuenta solo con funciones básicas de control.

### 3.2 Librerías del ESP32

En la carpeta “Microcontroller” se encuentran todas las bibliotecas necesarias desarrolladas para interactuar y manejar el microcontrolador. Estas bibliotecas están compuestas por funciones para configurar y controlar diferentes módulos, conexión WiFi, manejo de sensores y motores, además de las herramientas necesarias para la comunicación. Es decir, se compone de aquellas bibliotecas fundamentales para la programación del hardware. Estas son las siguientes:
- INA219: contiene aquellas bibliotecas destinadas a la configuración y manejo del sensor INA219, utilizado para la medición de carga de las baterías, además de la biblioteca correspondiente para realizar la lectura de la carga.
- Mapping: compuesta por las bibliotecas necesarias para realizar el mapeo, es decir, aquellas para la configuración del sensor, servo y la lógica para realizar el mapeo correspondiente.
- Connection: contiene las bibliotecas necesarias para gestionar las conexiones de red y la comunicación entre el microcontrolador y el backend.
- Core: incluye las bibliotecas necesarias para la comunicación, manejo de tareas concurrentes, almacenamiento de instrucciones y para realizar una copia del estado del sistema en un momento determinado.
- Lights: para el manejo de LED, indicador de errores.
- Motors: contiene las bibliotecas que permiten el control de los motores del vehículo.
- Utils: contiene una biblioteca que se encarga del manejo de string en formato JSON[28], los cuales se utilizan para la comunicación entre dispositivos.

Además del programa principal para el funcionamiento completo del sistema.

### 3.2.1 INA219

Contiene las bibliotecas necesarias para gestionar el componente INA219, el cual es utilizado para monitorear la carga de batería del sistema. Está compuesto por dos bibliotecas, las cuales se explicaran a continuación.

### 3.2.1.1 battery.h

Está compuesta por las funciones necesarias para inicializar y leer el nivel de carga del sensor de batería. Se definieron el minimo y maximo valor de carga (en V) como constantes:
- FULL_CHARGE: 8.4V
- MIN_CHARGE: 6.4V

Las funciones incluidas son:
- battery_sensor_init(): Realiza la inicialización, configuración y calibración del sensor INA219 para comenzar con la medición de la batería.
- battery_sensor_read(uint8_t *): Lee el estado de la batería y, luego de realizar las verificaciones necesarias y calcular el porcentaje según el voltaje leído, almacena el valor en la dirección indicada por el puntero recibido como parámetro.

### 3.2.1.2 ina219v2.h

Está biblioteca contiene las funciones necesarias para inicializar, configurar, obtener mediciones de voltaje, además de permitir las calibraciones del sensor INA219.

Se definió una única estructura denominada ina219_t que se utiliza para almacenar la dirección I2C del dispositivo. Además de esto, se definieron las siguientes constantes:
- INA219_ADDRESS: Dirección I2C por defecto del INA219, se puede modificar dependiendo del hardware. En este caso es la dirección 0x40.
Las siguientes se utilizan para almacenar las direcciones de los registros del INA219:
- INA219_REG_CONFIG: 0x00
- INA219_REG_SHUNT_VOLTAGE: 0x01
- INA219_REG_BUS_VOLTAGE: 0x02
- INA219_REG_POWER: 0x03
- INA219_REG_CURRENT: 0x04
- INA219_REG_CALIBRATION: 0x05
Por último, para la configuración del INA219:
- INA219_CONFIG_DEFAULT: Se establece en 0x299F, lo que significa modo normal, rango de 16V, y ADC 12 bits.
Las funciones incluidas en la librería son las siguientes:
- ina219_init(ina219_t *dev): Se utiliza para la inicialización del INA219.
- ina219_get_bus_voltage(ina219_t *dev, float *voltage): Obtiene el voltaje del bus en V. Esta es la que utilizaremos en nuestro caso.
- ina219_get_shunt_voltage(ina219_t *dev, float *voltage): Obtiene el voltaje del shunt en mV.
- ina219_get_current(ina219_t *dev, float *current): Se utiliza para obtener la corriente en mA.

- ina219_calibrate(ina219_t *dev, float shunt_resistance): Para la configurar la calibración.

Debemos aclarar que esta biblioteca, como se adelantó, es una adaptación de la biblioteca hecha por Ruslan V. Uss, y publicadas en Github.

### 3.2.2 Mapping

Dentro de está sección, se encuentran todas las bibliotecas que se encargan y facilitan el mapeo. Una parte fundamental es el manejo del sensor, para esto se utilizó una librería desarrollada por Artful Bytes[29] en GitHub. La misma está compuesta de 3 sub-librerías, encargadas del manejo de los elementos necesarios para llevar a cabo la tarea de medición. Estas son:
- Librería de control de los pines GPIO del ESP32
- Librería de control del sensor VL53L0X
- Librería de control de la comunicación I2C requerida por el sensor Cada una de estas se explicará a continuación.

### 3.2.2.1 mapping.h

Teniendo en cuenta el esquema físico del robot, se desarrolló esta librería que permite obtener el ángulo en el que el sensor esté apuntando, y la distancia a la que se encuentra del obstáculo.
El motivo por el cual se implementó fue para facilitar la obtención de los valores necesarios para generar el mapa. El sensor VL53L0X puede medir distancias, pero solo el servo sabe en qué dirección está apuntando. Por lo tanto, esta librería se encarga de tanto realizar las mediciones con el sensor, como de consultarle al servo el ángulo de giro en el que se encuentra.
Esta librería introduce las siguientes funciones:
- mapping_init(): realiza la inicialización necesaria para poder utilizar el servomotor y el sensor LiDAR. Esta función utiliza las inicializaciones previamente creadas (gpio_init(), i2c_init(), vl53l0x_init(), servo_initialize() y servo_start())
- getMappingValue(*angle, *distance): obtiene el ángulo actual del servo y la distancia medida por el sensor, y los guarda en las variables angle y distance respectivamente. En caso de que el sensor falle en tomar una medición, intentará reiniciarlo.
- mapping_pause(): esta función detiene el servomotor, y apaga el LiDAR, de tal manera que no gasten energía.

- mapping_restart(): se utiliza para reiniciar el servomotor.

### 3.2.2.2 vl53l0x.h

Esta librería incluye las funciones y definiciones necesarias para la inicialización, configuración y control del sensor VL53L0X. Como fue mencionado previamente, se utilizó una librería ya existente.
Se definió la siguiente constante:
- VL53L0X_OUT_OF_RANGE (500)
También se definió la siguiente estructura:
- vl53l0x_idx_t: para especificar el sensor, en este caso es VL53L0X_IDX_FIRST.
En lo que respecta al control del sensor VL53L0X, la librería está compuesta por múltiples funciones, pero las más importantes son funciones:
- vl53l0x_init(): realiza la inicialización del sensor VL53L0X, seteando su dirección I2C por default, y su configuración.
- vl53l0x_read_range_single(idx, *range): realiza una medición del sensor idx (al solo usar uno, este parámetro es obsoleto) y guarda el resultado en la variable range.
- vl53l0x_reset(): reinicia el sensor en caso de que exista algún fallo.

### 3.2.2.3 i2c_vl53l0x.h

La librería encargada de las comunicaciones I2C del sensor LiDAR posee múltiples funciones encargadas de, por ejemplo, escribir o leer registros de varios tamaños diferentes. Se definió la siguiente constante para almacenar la dirección por default del slave (VL53L0X):
- DEFAULT_SLAVE_ADDRESS (0x29)
Se definieron las siguientes estructuras:
- addr_size_t: para almacenar los diferentes tamaños de direcciones posibles, estas son ADDR_SIZE_8BIT o ADDR_SIZE_16BIT.
- reg_size_t: para almacenar los diferentes tamaños de registros posibles, estos son REG_SIZE_8BIT, REG_SIZE_16BIT y REG_SIZE_32BIT.
Además, está compuesta por las siguientes funciones:
- Funciones encargadas de leer de registros para diferentes tamaños de datos y de direcciones:
- i2c_read_addr8_data8(uint8_t , uint8_t *)
- i2c_read_addr8_data16(uint8_t , uint16_t *)

- i2c_read_addr16_data8(uint16_t , uint8_t *)
- i2c_read_addr16_data16(uint16_t , uint16_t *)
- i2c_read_addr8_data32(uint16_t , uint32_t *)
- i2c_read_addr16_data32(uint16_t , uint32_t *)
- Función encargada de leer una cantidad determinada de bytes de una dirección:
- i2c_read_addr8_bytes(uint8_t , uint8_t *, uint16_t )
- Funciones encargadas de escribir en registros para diferentes tamaños de datos y de direcciones:
- i2c_write_addr8_data8(uint8_t , uint8_t)
- i2c_write_addr8_data16(uint8_t , uint16_t)
- i2c_write_addr16_data8(uint16_t , uint8_t)
- i2c_write_addr16_data16(uint16_t , uint16_t)
- Función encargada de escribir una cantidad determinada de bytes en una dirección:
- i2c_write_addr8_bytes(uint8_t, uint8_t *, uint16_t)

### 3.2.2.4 gpio.h

La librería que maneja los pines GPIO se encarga de controlar el pin XSHUT del sensor. Esto le permite controlar el apagado y encendido del sensor, de forma tal que este pueda ser reiniciado en caso de suceder algún inconveniente, y además permite la modificación de la dirección I2C de uno o varios sensores al mismo tiempo. De esta manera, es posible tener múltiples sensores VL53L0X en simultáneo, cada uno con su propia dirección I2C.
Se define la siguiente constante:
- GPIO_XSHUT_FIRST: indica el número de pin para XSHUT, en este caso se utiliza el GPIO_NUM_23.
Además, se define también la siguiente estructura:
- gpio_t: almacena los tipos de GPIO posibles, estos son GPIO_XSHUT_FIRST, GPIO_XSHUT_SECOND y GPIO_XSHUT_THIRD.
La librería está compuesta por las siguientes dos funciones:
- gpio_init(): para inicializar el GPIO, configurandolo como salida y estableciendo un nivel bajo en el pin.
- gpio_set_output(gpio_num_t gpio, bool enable): para establecer el gpio en un nivel alto o bajo dependiendo del parámetro enable.

### 3.2.2.5 servo.h

El sensor LiDAR dispone de una biblioteca particular para su manejo, sin embargo, por encima de esta, se encuentra otra biblioteca la cual abstrae el funcionamiento del sensor, junto con el del Servomotor. La razón de esto, es por cómo funcionará el mapeo o sondeo del entorno. El sensor rota aproximadamente 360° mediante el servomotor, por lo que ambos deben operar en conjunto, debiéndose sincronizar el sondeo con la rotación.
Cabe aclarar que realmente el sensor no rota unos 360 grados pues, se enredara el cable y causando daños tanto al sensor, como al resto del robot. Para evitar esto, la pieza en la que el sensor está montado cuenta con unas aspas que accionan al fin de carrera al llegar a ciertos ángulos de giro, los cuales invierten el sentido de giro.
Siendo más específicos, el funcionamiento del servomotor es el siguiente: una vez configurado, el mismo espera a la orden de start (cuando se haya inicializado el LiDAR). A partir de ese instante, estará siempre rotando, salvo que se lo pause. Su dirección de giro se invertirá cada vez que una de las aspas del soporte del LiDAR accione el fin de carrera, pero manteniendo su velocidad (salvo que se indique lo contrario).
El accionar el fin de carrera no solo indica el cambio de sentido, sino que es el punto de referencia para el cálculo de la posición del servo (y por tanto del LiDAR). Ya que el servo gira continuamente, sin un momento de referencia sería imposible calcular su posición, por lo que cada vez que invierte su sentido de giro, también se re-establece una variable con dicho tiempo, la cual se utiliza para calcular el ángulo desde ese momento hasta que se invierta el sentido. Es decir, cada vez que se quiera obtener el ángulo como parte del cálculo se hará una resta entre dicho instante y el tiempo base, que, sabiendo la velocidad de giro y otros parámetros, nos permite calcular la posición.

Angulo = (BaseSpeed * (duty − STOP) * (TimeNow − TimeBase))/(DIFF * CF)

- BaseSpeed[s]: velocidad máxima giro del servo.
- Duty: Ciclo de trabajo de la PWM.
- STOP[us]: Ciclo de trabajo que indica al Servo detenerse
- TimeNow[us]: tiempo actual al llamar a la función (referencia al encendido del MCU)
- TimeBase[us]: tiempo referencia establecido al accionar el fin de carrera
- DIFF(Diferential)[us]: Diferencia entre STOP y la velocidad máxima.
- CF(Conversion Factor): Factor de conversión para pasar de us a s.

A partir de esta fórmula, se puede obtener los ángulos, no obstante como se dijo anteriormente, no se completa el giro, por lo que a esta fórmula se suma un ángulo Offset correspondiente al sentido por el que se presionó el final de carrera.

En cuanto al funcionamiento de todo esto, es considerablemente complejo, para esto la librería está compuesta por:
- Constantes:
- SERVO_MIN_PULSEWIDTH_US: Ancho de pulso mínimo (giro rápido en un sentido), se definió como 900.
- SERVO_MAX_PULSEWIDTH_US: Ancho de pulso máximo (giro rápido en el sentido opuesto), se definió como 2100.
- SERVO_STOP_PULSEWIDTH_US: Ancho de pulso para detener el servo, es 1500.
- SERVO_PULSE_GPIO: Se establece con el pin GPIO_NUM_14.
- SERVO_TIMEBASE_RESOLUTION_HZ 1000000: 1MHz, 1us per tick.
- SERVO_TIMEBASE_PERIOD 20000: 20000 ticks, 20 ms.
- Además de otras constantes que sirven para el cálculo de los ángulos y definición de las velocidades baja, media y alta (teniendo como referencia el ancho de pulso mínimo y máximo previamente mencionados).
- Estructura:
- SERVO_DIRECTION: compuesto de los valores UP y DOWN, facilita indicar el aumento o decremento de la velocidad..
- Funciones:
- servo_inialize(): esta función inicializa la PWM para controlar el servomotor, lo que implica la inicializar de un Timer así como, de una serie de estructuras que permiten operar el mismo, entre ellas, la inicialización de la interrupción accionada por el fin de carrera,.
- servo_start(): inicializa el servo a velocidad media.
- servo_stop(): detiene el servo.
- servo_pause(): detiene el servo, sin alterar el cálculo del ángulo.
- servo_restart(): reanuda el giro del servo (la contraparte de pause).
- readAngle(): retorna el ángulo al que apunta el servo.

- servo_set_speed(SERVO_DIRECTION): permite aumentar o disminuir la velocidad de giro. Los cambios se reflejan al invertir, para evitar alterar el cálculo de ángulo.
- servo_invert(): la función principal, permite invertir el giro, establecer el tiempo base o referencia, el ángulo de offset, y de ser indicado cambiar la velocidad.
- delete_servo_semaphores(): elimina todos los semáforos creados, esto se utiliza en caso de ejecutar ABORT.

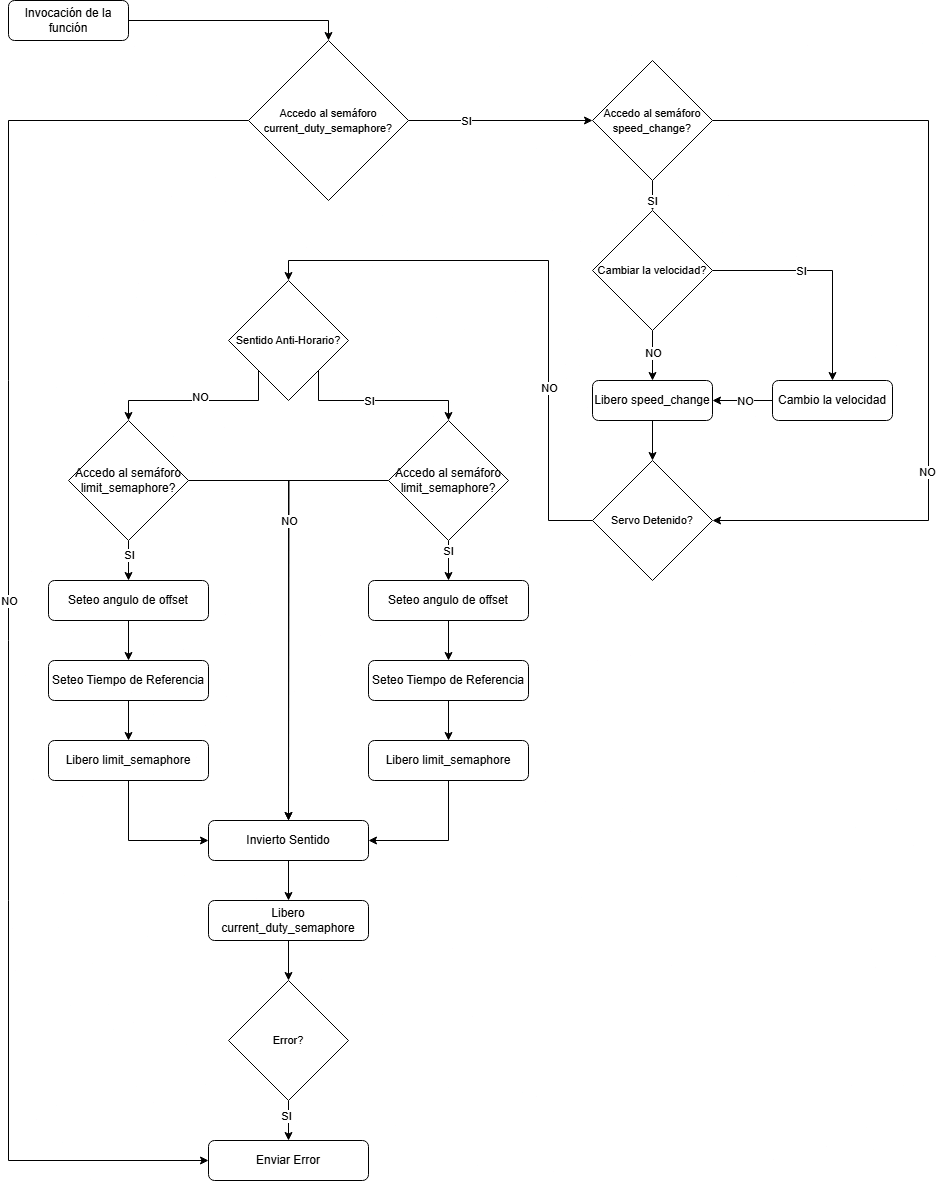
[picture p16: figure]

Figura 12: Diagrama de Flujo de la función servo_invert()

### 3.2.2.6 limit_switch.h

Como se mencionó anteriormente, una parte clave del funcionamiento del servomotor es el fin de carrera, el cual permite realizar la inversión del giro, el cálculo del ángulo y demás. Para esto, el mismo se implementó como una interrupción por hardware, de tal manera que al accionarse cierre el circuito conectado a GND el pin correspondiente, activando la interrupción. Y esta cambia el valor de un variable que sirve a modo de flag indicando que fue presionado. Además se considera el efecto rebote, por lo que se ignora cualquier interrupción hasta no haber pasado tiempo determinado desde la anterior (50ms).
Esta librería proporciona las funciones necesarias para controlar y gestionar el interruptor de límite, es decir, el fin de carrera. Para almacenar el número de pin del fin de carrera, se definió la siguiente constante:
- LIMIT_SWITCH_PIN GPIO_NUM_25
También, contiene las siguientes funciones:
- interrupt_init(): Esta función inicializa la configuración de la interrupción para el interruptor de límite, en nuestro caso el fin de carrera. Se encarga de configurar el pin para que genere interrupciones cuando pase de un nivel alto a bajo.
- check_limit_switch(): Está función verifica el estado del interruptor de límite (limit switch). En el caso de haber sido activo, indica que el servo alcanzó la posición límite (fin de carrera).
- delete_flag_semaphore(): Elimina el semáforo utilizado para modificar el flag que indica si el fin de carrera fue presionado o no, se utiliza al ejecutar ABORT.

### 3.2.3 Connection

Esta carpeta se utiliza para implementar las bibliotecas necesarias para el módulo de comunicación entre el microcontrolador ESP32 y el servidor, el cual es fundamental para el intercambio de datos. Utilizando el MCU configurado como un Access Point, se establece una red local donde otros dispositivos pueden conectarse. Esta configuración permite la transmisión de mensajes y comandos, como las instrucciones para controlar el vehículo o alertas de error.
En cuanto al protocolo de envío de mensajes, se optó por utilizar MQTT, y para la recepción de instrucciones HTTP, por las razones antes mencionadas..

### 3.2.3.1 ap_server.h

En principio, se creó el Access Point adaptando un programa existente brindado por ESP-IDF. En este programa se configuraron los parámetros de la red, como el nombre (SSID), la contraseña, el canal de comunicación y la cantidad máxima de conexiones simultáneas permitidas. Estos son parámetros fundamentales para que el ESP32 actúe como un punto de acceso, permitiendo que otros dispositivos se conecten para intercambiar información, como instrucciones de control del vehículo o mensajes de error, facilitando la comunicación dentro del sistema.
Se definen las siguientes constantes:
- ESP_WIFI_SSID: Nombre de la red creada, en este caso es: "Cyclops".
- ESP_WIFI_PASS: Contraseña de la red, la cual es "A2TdP2Lidar".
- ESP_WIFI_CHANNEL: Canal utilizado, se definió el canal 1.
- MAX_STA_CONN: Máxima conexión a la red, es 4.
- MAX_NUM_CONNECTIONS: Máximo número de conexiones, es 1.

Se divide principalmente en tres funciones:
- wifi_init_softap(): Esta función configura el ESP32 para que actúe como un Access Point. Inicializa la red WiFi y establece los parámetros de la red, como el SSID, la contraseña y el canal. Además, registra los manejadores de eventos necesarios para la conexión de clientes y la asignación de IP. Por último, inicia el WiFi, permitiendo que otros dispositivos se conecten a la red del ESP32 y envíen o reciban mensajes.
- initialize_server(): Inicializa la memoria flash NVS (almacenamiento no volatil) y configura el ESP32 como un Access Point mediante la función wifi_init_softap(), explicada previamente. Si ocurre un error al inicializar la memoria flash, la función la borra y vuelve a intentarlo.
- wait_for_client_connection(): Esta función se bloquea hasta que un dispositivo se conecte al Access Point. Utiliza un semáforo para esperar la conexión, lo que asegura que no continúe la ejecución hasta que se haya establecido una conexión.

### 3.2.3.2 mqtt_server.h

La biblioteca mqtt_server.h, encargada de llevar a cabo la comunicación entre el ESP32 y el Servidor, consta de 3 funciones principales:
- mqtt_start(): función que inicializa el servidor MQTT. Lo que implica configurar el ESP32 y conectarse al Broker MQTT.

- mqtt_disconnect(): esta función se encarga de desconectar el servidor MQTT.
- mqtt_publish(): esta función permite enviar un mensaje recibido por parámetro, en un tópico indicado por parámetro.

### 3.2.3.3 mqtt_handler.h

Esta biblioteca se diseñó para facilitar el envío y recepción de información mediante MQTT, y para ello consta de 6 funciones:
- getInstruccionMessage(): devuelve por referencia una instrucción recibida. Dicha instrucción es obtenida del instruction buffer antes mencionado.
- sendMappingValue(): esta instrucción recibe la distancia y ángulo, del LiDAR y Servo, y los envía mediante el tópico Mapping.
- sendBatteryLevel(): esta función recibe el nivel de carga en la batería obtenido mediante el INA219, y lo envía mediante el tópico Battery.
- sendErrorMessage(): esta función recibe un Tag(etiqueta de origen), y un mensaje, y los envía mediante el tópico Messages, marcado como un mensaje de error.
- sendWarningMessage(): idem al anterior, pero marca el mensaje como una advertencia.
- sendInfoMessage(): idem a los dos anteriores, pero marca el mensaje como información.

Un punto clave de estas funciones, y del manejo con MQTT, es que no se envía (ni recibe) texto plano, sino que utilizamos el formato JSON. Por lo que cada función crea un JSON acorde al dato a enviar. Y en caso de getInstruccionMessage() recibe y deserializa el JSON para obtener la instrucción. Cabe aclarar que todas las funciones devuelve si tuvieron éxito o no con su tarea, ya que son tipo esp_err_t.

### 3.2.3.4 http_handler.h

Esta librería contiene una única función necesaria para realizar una petición GET al backend para obtener la siguiente instrucción no leída y luego almacenarlo en un buffer para posteriormente ejecutar. Primero se define un tamaño máximo de mensaje con la siguiente constante:
- INST_MAX_SIZE 20
Esta función es:
- getHTTPInstruction(char *, size_t): realiza la petición GET al backend para luego con un manejador de eventos, obtener la instrucción y decodificarla, ya que está en formato JSON.

### 3.2.4 Core

Esta carpeta contiene la librerías centrales del funcionamiento del sistema, es decir, aquellas con funciones claves del sistema, entre ellas las librerías con la funcion de inicializacion del sistema, y las tareas que ejecutan las tareas claves, la librería con buffer de instrucciones, la de gestión del bus I2C, y la que nos permite abortar la ejecución del sistema.

### 3.2.4.1 checkpoint.h

Esta biblioteca permite ejecutar la acción ABORT, mediante una serie de funciones que permiten crear un “punto de guardado” y ejecutar dicho punto. En concreto, permite crear una copia del estado del sistema, y volver a él, abortando la ejecución actual del sistema. Consta de 2 funciones:
- setCheckpoint(): para realizar la creación del punto de guardado.
- activeCheckpoint(): para realizar los pasos necesarios para el ABORT (liberar recursos utilizados y abortar tareas) para luego activar el punto de guardado.

### 3.2.4.2 cyclops_core.h

Esta biblioteca contiene funciones que permiten facilitar la inicialización del sistema y el manejo de las tareas concurrentes del ESP32, utilizando FreeRTOS[30] para crearlas. Estas funciones son las siguientes:
- system_init(): se utiliza para la inicialización del sistema, iniciando motores, sensores, servidor AP y MQTT. Además de esperar la conexión del backend al mismo.
- createTasks(): Esta función se encarga de crear las tareas necesarias para el funcionamiento del sistema.
- abort_tasks(): Se encarga de finalizar las tareas en ejecución, en este caso la encargada de manejar las interrupciones del servo, liberando los recursos necesarios para el reinicio del sistema.

### 3.2.4.3 i2c.h

Para la comunicación entre el MCU y los sensores tanto el LiDAR como el INA219, como se explicó en el informe anterior se implementó una biblioteca para manejar el bus I2C. No obstante tras implementar las bibliotecas para conectar ambos sensores, se terminó modificando esta biblioteca reduciendola a las tareas esenciales de configurar la conexión I2C, y arbitrar el acceso al bus. La razón tras esta decisión fue, la complejidad en la forma de operar y utilizar el bus por parte de ambos sensores, lo que devino en crear librerías aparte para cada uno, y en limitar esta a las funcionalidades anteriormente mencionadas.
Se definieron las siguientes constantes:
- I2C_MASTER_SCL_IO GPIO_NUM_22
- I2C_MASTER_SDA_IO GPIO_NUM_21
- I2C_MASTER_NUM I2C_NUM_0
- I2C_MASTER_FREQ_HZ: 400000
- I2C_MASTER_TX_BUF_DISABLE: 0
- I2C_MASTER_RX_BUF_DISABLE: 0
- I2C_MASTER_TIMEOUT_MS: tiempo de timeout de I2C en ms, en este caso se le asignó 1000 ms.

Con respecto a las funciones, contiene las siguientes:
- i2c_init(): esta función inicializa al ESP32 como I2C en modo Master, configurando los pines SDA y SCL en modo pull-up, y la frecuencia en 400KHz correspondiente a Fast I2C. Además inicializa un semáforo para bloquear el acceso simultáneo al bus..
- i2c_get_bus(): esta función chequea si el bus i2c está libre, y de estarlo lo toma, bloqueandolo para cualquier otro dispositivo.
- i2c_give_bus(): esta función es la contraparte de la anterior. Si el dispositivo terminó de operar sobre el bus, lo libera para su uso.
- i2c_delete_bus(): esta función se utiliza para eliminar el semáforo utilizado para el bus.

### 3.2.4.4 instruction_buffer.h

Debido a la diferencia de velocidad con la que puede recibir y atender instrucciones el MCU, se creó esta biblioteca, la cual permite almacenar las instrucciones entrantes en un buffer circular, para que la tarea encargada de ejecutarlas las tenga cuando sea necesario. De esta manera, no se pierden instrucciones.
Para determinar el tamaño del buffer, se definieron las siguientes constantes:
- INSTRUCTIONS_BUFFER_SIZE: Cantidad de instrucciones que se pueden almacenar en el buffer, se determinó 10 instrucciones como máximo.

- INSTRUCTION_MAX_LENGTH: Máximo largo de cada instrucción, en este caso es 40. Además de esto, se incluyeron las siguientes funciones:
- initBuffer(): realiza la creación del semáforo necesario para gestionar el acceso al buffer, devuelve error en caso de fallar.
- getInstruction(char *): devuelve la siguiente instrucción del buffer y actualiza los punteros necesarios. En caso de no haber nuevas instrucciones, devuelve error de timeout.
- saveInstruction(char *): almacena una nueva instrucción en el buffer y actualiza los punteros necesarios. En el caso de no haber espacio en el buffer, retorna error.
- delete_buffer_semaphore(): elimina el semáforo previamente creado, se utiliza en el caso de ejecutar un ABORT.

### 3.2.5 Lights

### 3.2.5.1 lights.h

La carpeta lights contiene una única librería, la cual se encarga de gestionar el control de las luces del sistema, en este caso un único LED de error.
Está libreria esta compuesta por las siguientes funciones para inicializar y controlar el estado del LED:
- lights_init(): Realiza la inicialización y configuración de los pines utilizados para los leds.
- error_led_on(): Establece el pin del led en un nivel alto para encenderlo e indicar que un error ocurrió.
- error_led_off(): Establece el pin del led en un nivel bajo para apagarlo.
- led_blink_task(time_ms): crea una tarea que hace titilar el led, en base al tiempo de entrada. Si la tarea ya se encuentra creada, la elimina, deteniendo el titileo y apagando el led.

### 3.2.6 Motors

### 3.2.6.1 motors.h

Para el manejo de los motores, se desarrolló una librería en el framework ESP-IDF que, en conjunto del driver L9110s [31], permite el desplazamiento del robot. Esta realiza diferentes movimientos como avanzar, retroceder, rotar a la derecha, y rotar a la izquierda.

Se definieron las siguientes constantes para almacenar el número de pin de control para los motores:
- MOTOR1_PIN1: pin de control para Motor 1 (dirección 1), se le asignó el GPIO_NUM_19.
- MOTOR1_PIN2: pin de control para Motor 1 (dirección 2), se le asignó el GPIO_NUM_18.
- MOTOR2_PIN1: pin de control para Motor 2 (dirección 1), se le asignó el GPIO_NUM_5.
- MOTOR2_PIN2: pin de control para Motor 2 (dirección 2), se le asignó el GPIO_NUM_17.
Además, las siguientes estructuras:
- MOTOR_STRUCT: se utiliza para almacenar el estado del pin 1 y 2 de cada motor.
- DIRECTIONS: se almacenan las distintas direcciones posibles, estas son las siguientes FORWARD, BACKWARD, ROTATE_RIGHT, ROTATE_LEFT y STOP. La misma presenta también las siguientes funciones:
- motors_setup(): inicializa los pines que controlan los motores y se asegura que los motores estén apagados poniendo los pines en bajo.
- motors_command(direction): controla la dirección de giro de los motores, permitiendo que estos desplacen al robot hacia adelante, hacia atrás, que rote con sentido de giro hacia la derecha y hacia la izquierda.

### 3.2.7 Utils

Esta carpeta incluye la biblioteca json_helper.h, la cual fue desarrollada para facilitar el manejo de mensajes en formato JSON. Es fundamental para manejar y facilitar la comunicación entre los distintos componentes del sistema.

### 3.2.7.1 json_helper.h

Esta biblioteca está compuesta por las funciones necesarias para crear, procesar y visualizar objetos de tipo JSON. Aquellas son:
- create_json_data(char **, const char **, const char **, const size_t): Realiza la creación de un string de formato JSON, a partir de pares clave-valor.
- deserealize_json_data(const char *,char *, const size_t): Realiza el parseo de un string en formato JSON y extrae los valores asociados a determinadas claves o keys.

- print_json_data(const char *): Imprime el string de formato JSON recibido por argumento, para la depuración del sistema, en el caso de ser NULL, imprime un mensaje de error.

## 4 Documentación Relacionada

### 4.1 Interfaz Web

Para el desarrollo del frontend del proyecto, se diseñó una página web utilizando Angular, con la cual se pueda controlar el vehículo, así cómo también visualizar el mapa generado con los obstáculos detectados por el sensor y los mensajes de control del vehículo. Permite facilitar al usuario la supervisión y control del sistema. Sus funcionalidades principales son:
- Monitoreo de datos: cuenta con un monitor donde se pueden visualizar cualquier tipo de mensajes, ya sean de error o informativos.
- Visualización de mapa: Se presenta un gráfico en 2D, donde se representan los puntos detectados por el sensor LiDAR.
- Sidebar: Incluye botones interactivos que permiten enviar instrucciones al vehículo, como ajustar su velocidad o pausar el mapeo.

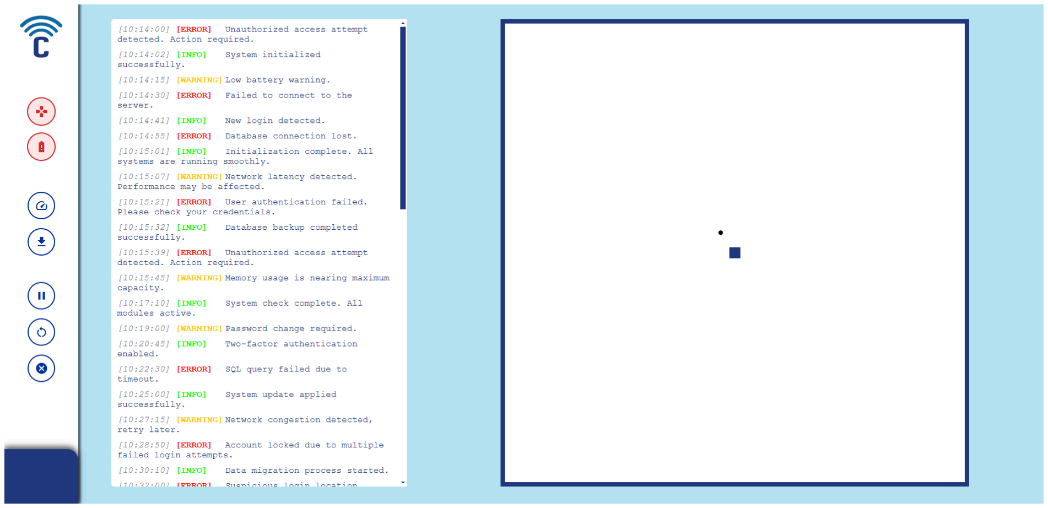
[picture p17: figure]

Figura 13 : Interfaz web desarrollada.

En la figura anterior se pueden observar todos sus componentes principales incluyendo: sidebar, monitor y mapa.

Asimismo, el sidebar es un componente interactivo, por lo que puede expandirse o contraerse al hacer click sobre este. Este comportamiento se puede observar en la siguiente figura.

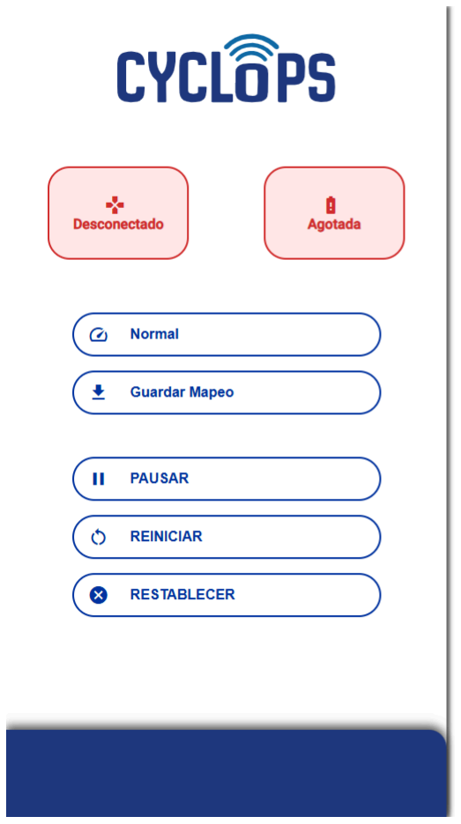
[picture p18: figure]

(a) Sidebar contraída | (b) Sidebar expandida

Figura 14 : Componente sidebar de la interfaz.

### 4.2 Hardware

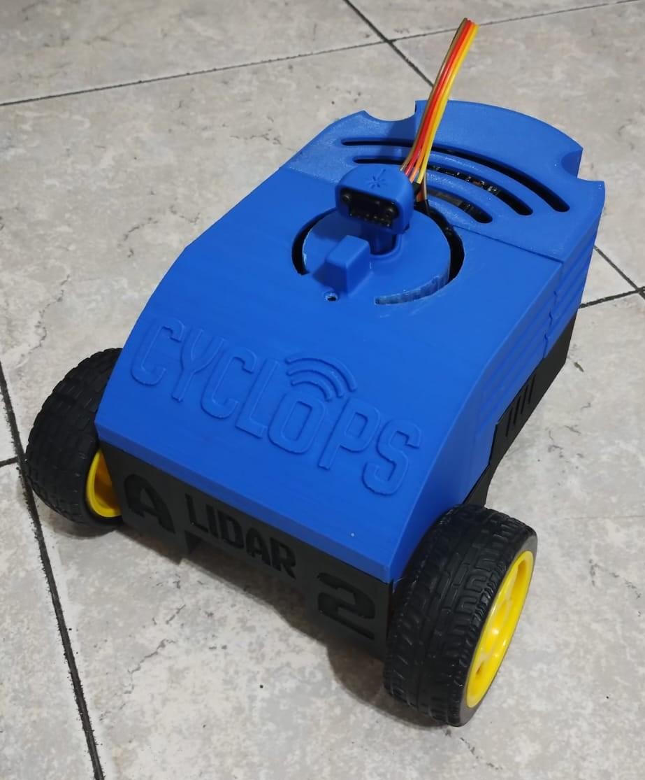
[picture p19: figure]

Imagen 2: Cyclops

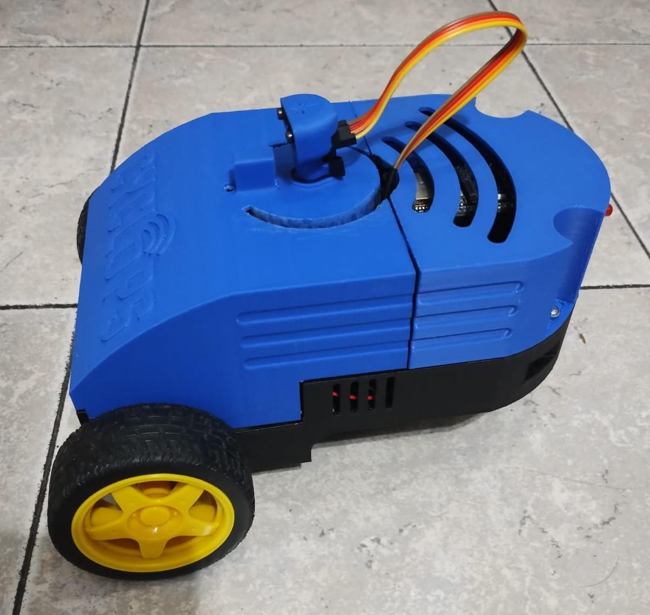
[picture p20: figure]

Imagen 3: Cyclops Vista Lateral

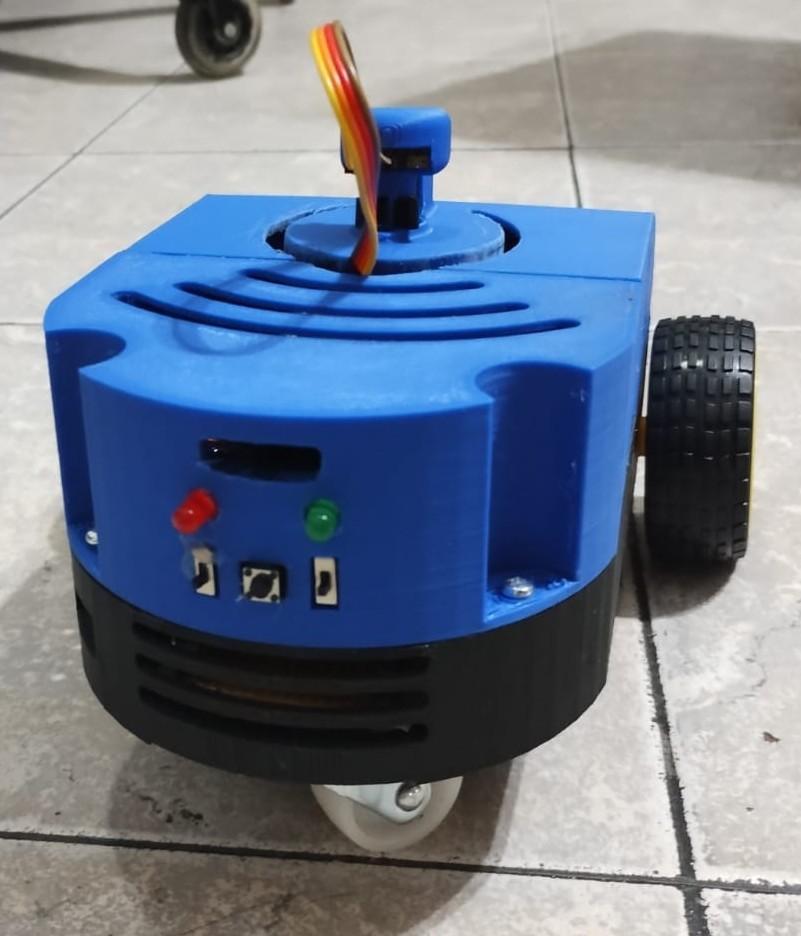
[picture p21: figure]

Imagen 4: Cyclops Vista Trasera

En esta última imagen podemos observar una serie de leds y botones importantes para el control del vehículo.
Los Leds como se explicó anteriormente, tienen dos funciones, el led verde(derecha) se enciende siempre que haya energía, indicando que el vehículo está encendido. Y el rojo, indica algún problema u estado especial.
Respecto a los botones, de izquierda a derecha tenemos el conmutador, el cual nos permite seleccionar entre la batería o la fuente de alimentación, como alimentación. Siguiendo, tenemos en el centro el botón de reinicio, que reinicia el ESP32; y por último el de ON/OFF para prender y apagar el robot.

### 4.3 Manual de Usuario

Para manejar el robot se debe utilizar la interfaz web, mediante la cual contaremos con una serie de controles básicos, y un mando que mediante la misma, nos permitirá controlar el robot.

### 4.3.1 Interfaz Web

La interfaz web cuenta con tres componentes principales, los cuales son el monitor donde se visualizan los mensajes que envía el robot, el mapa donde se encuentran los obstáculos detectados por el LiDAR; los cuales se pueden apreciar en la figura 13. Y por otro lado el sidenav (figura 14), donde se encuentran los botones para controlar el robot, así como el indicador de mando conectado, y el de carga de la batería.
Dichos botones son:
- Velocidad: el primer botón permite incrementar y decrementar la velocidad de giro del servo, y por tanto del proceso de mapeo.
- Guardar Mapeo: genera una captura local en la pc del estado actual del mapa.
- Pausar/Reanudar: pausa/reanuda el proceso de mapeo.
- Reiniciar: reinicia el robot.
- Restablecer: aborta el flujo actual de ejecución, es decir, aborta todas las tareas, y vuelve al estado previo a la creación de las mismas.

Debemos mencionar que los botones de Velocidad y Restablecer se encuentran inhabilitados, pues no se terminaron de implementar dichas funcionalidades.

### 4.3.2 Mando

Para controlar el robot, y en específico, manejarlo se optó por el uso de un mando, pues era mucho más sencillo, e intuitivo.

Botón | Acción

Tabla 2: Controles del Robot

La tabla anterior ilustra las funciones de los botones utilizados del mando para operar el robot. Como se puede observar no todos los botones se utilizan, por lo que a futuro se pueden asignar más funciones a estos.

Un detalle a mencionar es que el robot frena siempre que se suelte el Joystick Derecho, no obstante también se puede utilizar el R2.

### 4.4 Enlaces

En esta sección adjuntamos los links, para acceder al repositorio en github del código fuente, así como a la bitácora del proyecto y el video de demostración:

- Enlace a Github (https://github.com/tpII/2024-A2-LIDAR-Vl53l0)
- Enlace a la Bitácora (https://github.com/tpII/2024-A2-LIDAR-Vl53l0/blob/master/Doc/Bitacora.txt)
- Video Demostración del Proyecto (https://drive.google.com/drive/folders/1wUbKBuMYcJ_5Qg_DsekvTVtX-W3ThpmU?usp=sharing)
START | Reiniciar el Robot
SELECT | Abortar Ejecución
Triángulo | Aumentar Velocidad de Mapeo
X | Reducir Velocidad de Mapeo
Joystick Derecho ⬆️ | Avanzar
Joystick Derecho ⬇️ | Retroceder
Joystick Derecho ➡️ | Girar Derecha
Joystick Derecho ⬅️ | Girar Izquierda
R2 | Frenar el Auto

## 5 Conclusión

Después del primer informe de avance, se logró integrar todos los componentes planteados de forma exitosa, permitiendo llevar a cabo el funcionamiento general del sistema. Mediante el uso del microcontrolador ESP32, se diseñó un vehículo robot capaz de desplazarse y comunicarse con otros dispositivos. En simultáneo a esto, el mismo es capaz de estimar la presencia de distintos obstaculos a su alrededor. No obstante, considerarlo un mapeo propiamente dicho sería quizás una exageración, puesto que las limitaciones tecnológicas del sistema nos impiden realizarlo con una precisión adecuada para su comprensión.
Fue posible desplegar una página web en donde el usuario puede interactuar con el sistema, y enviar instrucciones al robot, permitiendo tanto el desplazamiento del mismo, como ir hacia adelante o para atrás, y girar tanto a la izquierda como a la derecha, así como el reinicio del microcontrolador, y el pausado y reanudado del sistema de mapeo. Cabe destacar, que para la correcta integración del sistema, fue requerida la implementación de un backend encargado de gestionar las comunicaciones con la página web y el microcontrolador.
En cuanto a los objetivos planteados inicialmente, a pesar de los parciales resultados obtenidos a la hora de realizar un mapeo como tal, fue posible alcanzar el resto de ellos, teniendo un sistema funcional que cumple con lo requerido.

### 5.1 Mejoras

Existen diversos aspectos que pueden ser mejorados en un futuro para la optimización del sistema. Entre estos se encuentran:
- Optimizar los tiempos de carga de los datos provenientes del backend al frontend.
- Optimizar el proceso por el cual se realiza el gráfico.
- Incorporar al mapa generado, el desplazamiento del vehículo, considerando los movimientos que realiza.
- Implementar la funcionalidad del cambio de velocidad de giro del servomotor.
- Mejorar el procesamiento de datos generados por el conjunto servomotor - sensor LiDAR, de forma tal que se pueda obtener un mapeo de mayor precisión y viabilidad.
- Respecto al sensor LiDAR, sería recomendable utilizar la librería oficial de control del mismo, ya que la misma permite realizar diferentes tipos de medición y calibración.

- Realizar las modificaciones necesarias para poder recibir instrucciones entre el ESP32 y el backend mediante el protocolo MQTT, y no por HTTP.
- Materializar el circuito realizado en un PCB.

Si se considera posible mejorar y/o reemplazar partes del sistema en sí mismo, recomendamos combinar el servomotor y lidiar con un giroscopio y/o encoder, para obtener los ángulos con precisión, o si fuera posible un motor con encoder, para mayor precisión y simplicidad del circuito.

## 6 Bibliografía

1. LiDAR. URL: https://www.ibm.com/mx-es/topics/lidar
2. ESP32. URL: https://www.espressif.com/en/products/socs/esp32
3. Linorobot by Rud Merriam. Hackaday. URL: https://hackaday.com/2016/03/13/petite-package-provides-powerful-robot/
4. ROS. URL: https://www.ros.org/
5. VL53L0X. URL:
https://www.st.com/en/imaging-and-photonics-solutions/vl53l0x.html
6. INA219. URL: https://www.ti.com/product/es-mx/INA219
7. HTTP. URL: https://kinsta.com/es/base-de-conocimiento/que-es-una-peticion-http/
8. IOT. URL: https://es.m.wikipedia.org/wiki/Internet_de_las_cosas
9. MQTT. URL: https://mqtt.org/
10. SG90. URL: https://www.alldatasheet.es/datasheet-pdf/pdf/1572383/ETC/SG90.html
11. I2C. URL: https://es.m.wikipedia.org/wiki/I%C2%B2C
12. PCB. URL: https://es.m.wikipedia.org/wiki/Circuito_impreso
13. Github. URL: https://github.com/
14. Proteus. URL: https://www.labcenter.com/
15. Pilas | 18650. | URL:
https://ferretronica.com/products/bateria-recargable-18650-3-7v-400-mah
16. VScode. URL: https://code.visualstudio.com/
17. PlatformIO. URL: https://platformio.org/
18. Mosquitto. URL: https://mosquitto.org/
19. MongoDB. URL: https://www.mongodb.com/es
20. Node. URL: https://nodejs.org/es
21. Open Source. URL: https://es.m.wikipedia.org/wiki/Sistema_de_c%C3%B3digo_abierto
22. Fundación Eclipse. URL: https://www.eclipse.org/
23. ESP-IDF. URL: https://idf.espressif.com/
24. JDK. URL: https://www.oracle.com/ar/java/technologies/downloads/
25. Maven. URL: https://maven.apache.org/
26. Spring-Boot. URL: https://docs.spring.io/spring-boot/index.html
27. Angular. URL: https://angular.dev/overview
28. JSON. URL: https://es.wikipedia.org/wiki/JSON

29. LiDAR Library. URL: https://github.com/artfulbytes/vl6180x_vl53l0x_msp430
30. FreeRTOS. URL: https://www.freertos.org/
31. Driver | L9110s. | URL:
https://naylampmechatronics.com/drivers/66-driver-puente-h-l9110s.html

## 7 Apéndice A: Materiales y Presupuesto

A continuación se detalla una lista de los materiales utilizados en el robot, incluyendo las cantidades y precio de cada uno.

COMPONENTE | CANTIDAD | PRECIO | NOTA
ESP32 | 1 | $13.400,00 | Dado por La Cátedra
LiDAR VL53L0X | 1 | $18.000,00 | Dado por La Cátedra
Motor DC | 1 | $3.700,00 | Dado por La Cátedra
Rueda Motor | 2 | $2.200,00 | Dado por La Cátedra
Rueda Loca | 1 | $4.700,00 | Dado por La Cátedra
Fuente (Integrado) | 1 | $5.570,00 | Dado por La Cátedra
Fuente (Cargador) | 1 | $8.000,00 | Dado por La Cátedra
Servomotor | 1 | $10.000,00 | Dado por La Cátedra
Dual Driver Motores | 1 | $3.000,00 | Dado por La Cátedra
INA219 | 1 | $10.928,00 | -
Pila 18650 | 2 | $3.860,00 | -
Step Down | 1 | $3.300,00 | -
Bornera | 2 | $600,00 | -
Placa Perforada | 1 | $3.450,00 | -
Fin de Carrera | 1 | $700,00 | -
Resistencias | 4 | $300,00 | -
Pines Hembra y Macho x 40 | 3 | $4.000,00 | Cantidad estimativa
Cobertor Pines Macho x 40 | 2 | $2.800,00 | -
Tornillos M3 | 15 | $115,00 | -
Tornillos M2 | 2 | $600,00 | -
Impresión 3D | 1 | $50.500,00 | -
Total | | $170.293,00

Tabla 3: Presupuesto del Proyecto

Los materiales listados, se componen de aquellos dados por la cátedra, y los adquiridos por nuestra cuenta de modo de completar el proyecto. Entre estos últimos, se destacan las piezas impresas que conforman el robot, y la INA219 para medir las pilas, las cuales también fueron puestas por nuestra cuenta.

Cabe destacar que además de los componentes ilustrados, se adquirieron otros, que por distintas razones, no están el proyecto final, razón por la cual no están presentes en el listado. Un ejemplo de esto, es el PCB que se descartó, por el error cometido al diseñar el circuito.

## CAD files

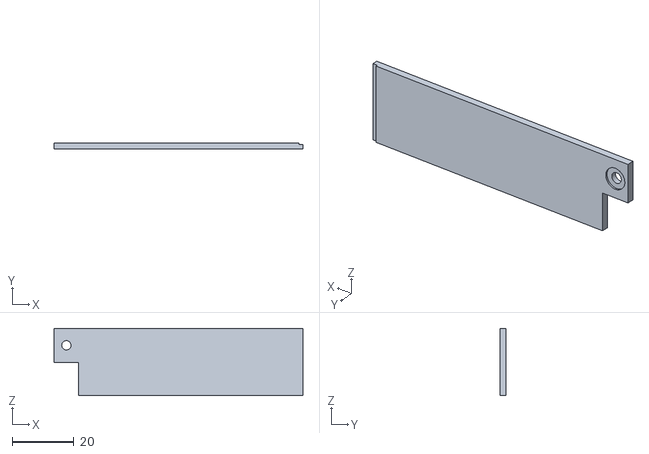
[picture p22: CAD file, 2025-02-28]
Doc/3D/MotorSupportv2.STL
80.5 x 2.00 x 21.8

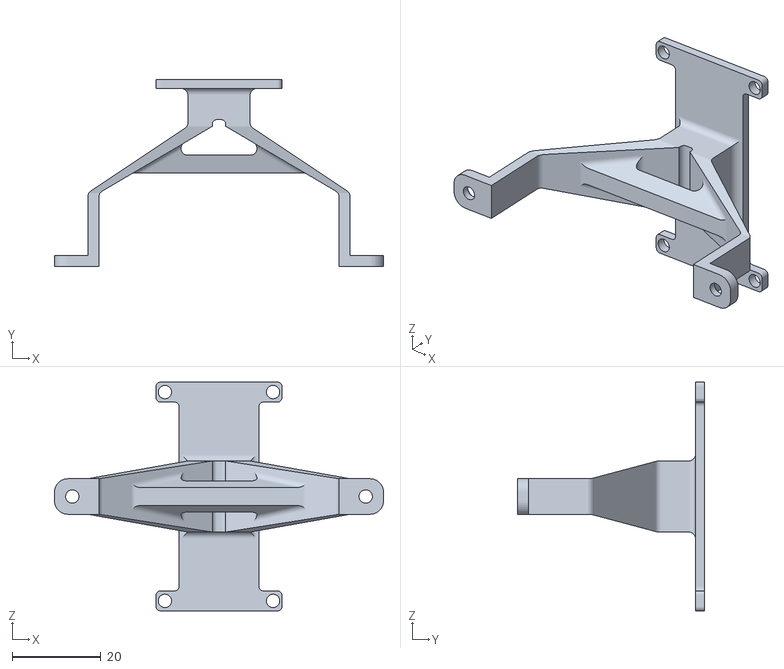
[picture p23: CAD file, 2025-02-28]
Doc/3D/ESP_HOLDERv2.STL
74.0 x 42.0 x 51.5

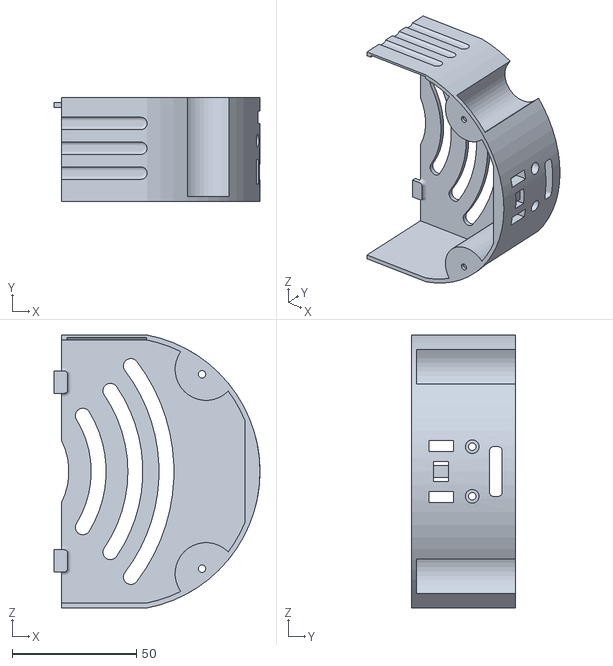
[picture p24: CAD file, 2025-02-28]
Doc/3D/UpBackv2.STL
83.0 x 42.0 x 110.0

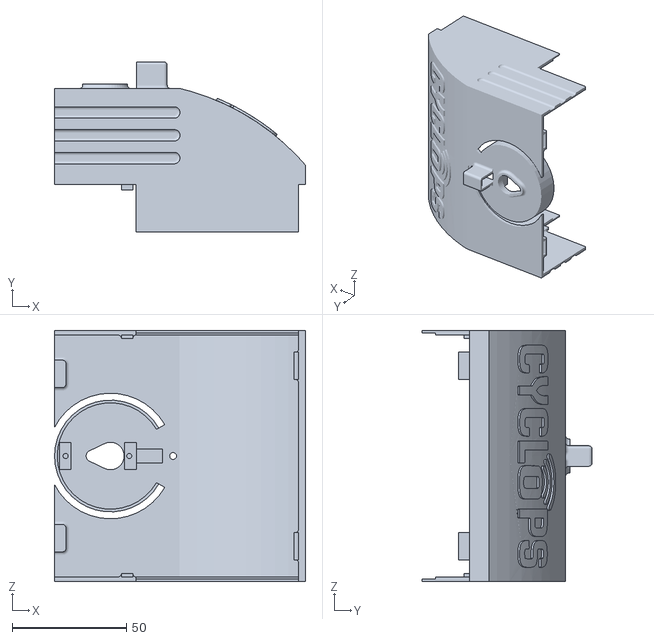
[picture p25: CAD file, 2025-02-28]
Doc/3D/UpFrontv2.STL
110.0 x 74.7 x 110.0

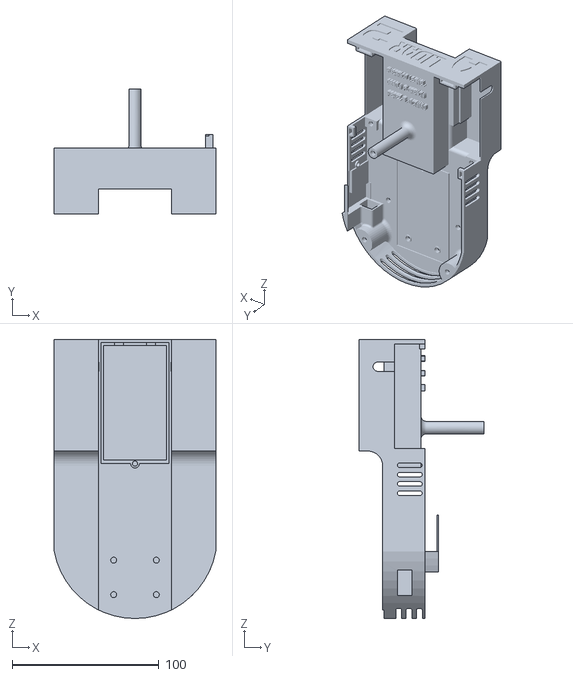
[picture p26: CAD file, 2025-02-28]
Doc/3D/Chasis.STL
110.0 x 85.0 x 190.0

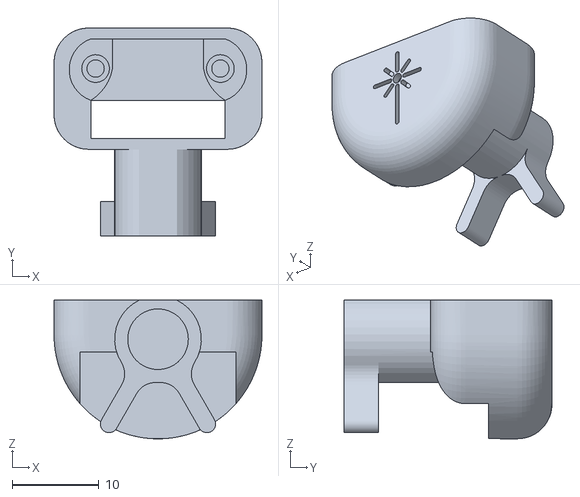
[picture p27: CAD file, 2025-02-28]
Doc/3D/LiDAR_Holder.STL
24.0 x 24.0 x 16.0

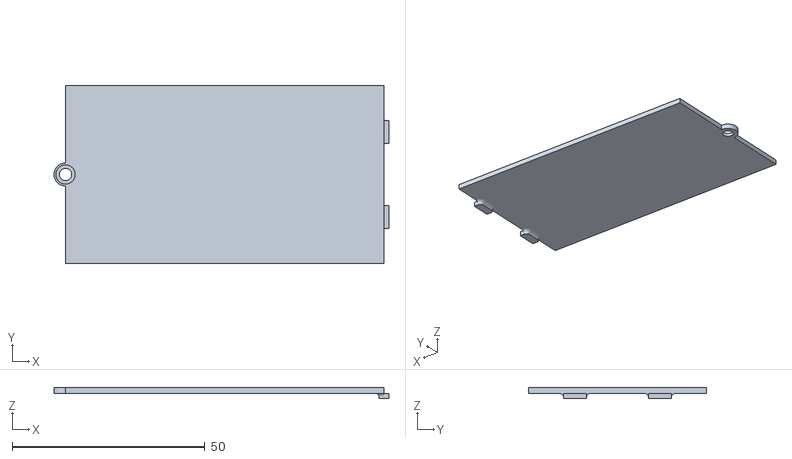
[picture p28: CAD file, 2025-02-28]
Doc/3D/BatteryCover.STL
86.8 x 46.0 x 2.80

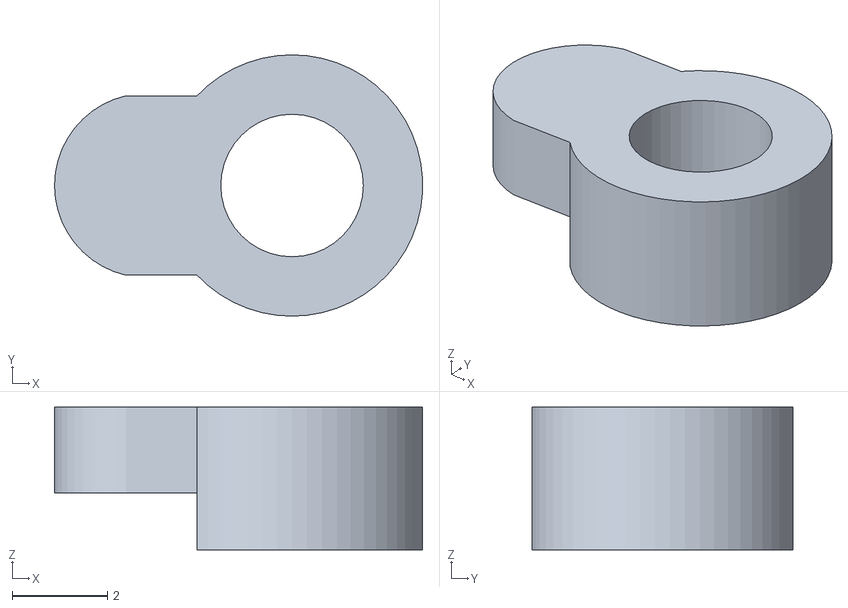
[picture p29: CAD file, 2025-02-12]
Doc/3D/PSSupport.STL
7.75 x 5.50 x 3.00

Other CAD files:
Doc/3D/MotorSupport2v2.STL

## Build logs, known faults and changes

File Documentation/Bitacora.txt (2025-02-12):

Bitacora

Durante el mes de agosto y hasta el 12 de Septiembre se realizo principalmente trabajo de investigacion sobre como realizar el royecto.
Principalmente sobre como realizar el mapeop, que tecnologias utilizar, y demas. 
Y por otro lado se realizo el dise;o prototipo del vehiculo.

15 de Septiembre

Se creo el workspace para el backend, frontend, y mcu. 
Y se implemento la DB y el primer controlador en el back, lograndoc crear, y obtener mensages desde la db.

16 de Septiembre

Se creo el servicio para comunicar el back con el ESP32
Se crearon las librerias i2c y lights para el MCU

19 de Septiembre
Creacion de las librerias http
Creacion del Diagrama electrico 

24 y 25 de Septiembre
Correccion de las librerias http

26 de Septiembre
Correccion de las librerias i2c y lights
Implementacion inicial de libreria para sensor lidar
Inicio de impresion de la parte principal del vehiculo
Inicio del diseño del PCB

28 de Septiembre
Se creo la libreria ap_server para configurar al ESP32 como un Access Point
Impresion completada 
- Fallas de diseño encontradas y pendentientes de arreglo

29 de Septiembre
Se agrego servidor TCP en la libreria ap_server

30 de Septiembre
Creacion de Interface, Service y Controller de la entidad SensorValue
Creacion de entidad Instruction junto con su Interface, Service y Controller.

01 de Octubre
Se generó la carpeta "Build" dentro de "Microcontroller"

02 de Octubre
Se agrego el servidor http 

04 de Octubre
Se creó la librería de control de los motores DC
Nos reunimos y testeamos las librerias de motores y wifi AP y ambas funcionaron como se esperaba
Esto implico testear los motores, el driver, y la fuente.
El diseño 3D tiene defectos a corregir

11 de Octubre
Se realizaron correciones al diseño 3D del pa parte princiapl, y se continuo con las partes superiores
Se testeo la libreria HTTP del MCU al BACKEND y funcionan.

14 de Octubre
Se opto por implementar MQTT en ves de HTTP entre el MCU y el backend
Se implmento MQTT en el BACKEND

21 de Octubre
Se creó la librería de control del sensor VL53L0X

23 de Octubre
Se implemento una libreria para el tratamiento de datos JSON
Se implemento una libreria MQTT Server para configurar y gestionar la conexion MQTT
Se implemento una libreria instruction buffer para intermediar en el recibimiento de informacion, de modo de no perder informacion mientras se ejecute otras tareas.
Se implemento una libreria MQTT Handler para abstraer la funciones de envio y recepcion de informacion
Se finalizo el testeo de MQTT tanto para recibir como para envio, de manera satisfactoria. Esto incluyo el testeo exitoso del reinicio remoto.
Se implemento la libreria checkpoint de modo de generar un punto de retorno en el programa. Para en un futuro implementar una  funcion que permita abortar el flujo de ejecucion del programa y volver a punto seguro.
Se eliminaron las librerias HTTP_SERVER y HTTP_Handler, ya reemplazas por MQTT

24 de Octubre
Se actualizó la librería de control del sensor LiDAR

31 de Octubre
Se agrego la libreria para la comunicacion con el Backend

3 de Noviembre
Se organizo el frontend, y se crearon los componentes base vacios.
Se implemento la base del sidenav y la estructura basica de la pagina.
Se modifico la libreria de mqtt_server por compatibilidad de datos recibidos y backend_comm para agregar tags en los mensajes al backend.

06 de Noviembre
Se actualizó la librería de control del sensor VL53L0X.
La misma ahora es funcional y provee la distancia a objetos.

9 de Noviembre
Se modifico la libreria mqtt_handler para el envio de tags y tipo de mensajes (warning, error, info)

13 de Noviembre 
Se agrega libreria para testeo del monitor en la pagina web.

15 de Noviembre
Se agrego identacion y timestamp en los mensajes del monitor.

16 de Noviembre
Libreria de mensages terminado, todo funcionando y testeado con el backend.
Se testeo y mejoro la libreria lights

18 de Noviembre
Se agrego la libreria INA219 I2C

19 de Noviembre
Se crearon los prototipos de los botones del sidebar.

20 de Noviembre 
Se agrego la libreria para visualizar mapa con obstaculos detectados (Testeo de d3.js con datos de prueba)

22 de Noviembre
Se realizaron mejoras con respecto a la visualizacion del mapa (cambios en el diseño).
Se agrego funcion para generar puntos de forma aleatoria para testeo.
Funcion para capturar el mapa en un momento determinado (falta mejorar).

23 de Noviembre
Implementado el componente para leer un joystick y poder controlar el robot. 
Pendiente crear el servicio y apartado visual.

27 de Noviembre
Se modifico la libreria para visualizar mapa, para que al hacer click sobre este se expanda o vuelva a su tamaño normal.
Se modifico la libreria del monitor para que al hacer click se expanda o vuelva a su tamaño original.

01 de Diciembre
Merge de librerias de monitor y map.
Se modifico la libreria monitor (merge ya realizado) para visualizar mapa y monitor al mismo tiempo. 
Ademas de agregar cambios necesarios para que cuando un componente se expanda el otro se contraiga.

02 de Diciembre
El sidneav mustra el status de conexion del Gamepad.
El gamepad es correctamente leido, y que pendiente implementar la comunicacion con el backend.

03 de Diciembre
Se modifico libreria del monitor para que cuando el mapa se expanda, se oculte el monitor.
Ademas, se realizaron mejoras en la visualizacion al expandir/contraer.

04 de Diciembre
El envio de instrucciones funciona, botones pendiente de asignar acciones
Mejora del componenete gamepad
Realizo modificaciones en el diseño de los botones del sidebar
Monitor frontend funcionando, queda pendiente la scrollbar y ajustes esticos

05 de Diciembre
Se agrego documentacion de las librerias mqtt_handler, mqtt_server, lights, i2c, json_helper e instruction_buffer.
Se agrego Swagger para documentacion del Backend

06 de Diciembre
Se arreglo el error al expandir/contraer los componentes.

08 de Diciembre
Se agrego todos los componentes en la pagina web y modifico el tamaño de estos.
Se modifico para que reciba los puntos a graficar desde el backend en el mapa.
Se empezo a integrar todas las funcionalidades en el MCU, y a su testeo.
Se ensamblo el robot.

09 de Diciembre
Funcionalidad de botones

10 de Diciembre
Se detectaron 3 Fallas Graves
- El Backend no se conecta a MQTT en la Notebook.
- MQTT crashea con los semaforos de FreeRTOS, por tanto no puede recibir datos.
- La conexion I2C del PCB no funciona, posiblemente por ruido en las pistas.

-- 2025 --

2 de Enero
Se re-diseno el robot para tener mas espacio para las conexiones
Se soluciono el Problema del Backend en la notebook
- Se reemplazo localhost por la IP asignada directamente al server por el ESP32.

3 de Enero
Se testeo libreria para anadir el desplazamiento del robot en el mapa.
Testeo desplazamiento de auto en mapeo.

7 de Enero
Se incio el testeo de los sensore LiDAR y INA219 en simultaneo

8 de Enereo
Los sensores funcionan en conjunto

11 de Enero
No se logro solucionar el conflicto MQTT - FreeRTOS
- Se reemplazara al recibir MQTT por HTTP en el backend.

12 de Enero
Se agrego TCP server
Se agrego la tarea y funciones correspondientes para recibir instrucciones por HTTP

13 de Enero
Se envio a imprimir el robot

15 de Enero
Correccion de errores en tarea para recibir instrucciones por HTTP

20 de Enero
Revision de errores en libreria HTTP y tarea para recibir instrucciones

23 de Enero
Modifico para que reciba lista de puntos desde el backend
Se testeo el ESP32 y funciona

27 de Enero
Se ensamblo el robot exitosamente, y se comprobo el funcionamiento de todo lo electronico.

31 de Enero
Se realizo el primer testeo del frontend conectado al Sistema
Se detecto Memory Leaks en el ESP32

04 de Febrero 
Se solucionaron los Memory Leaks
Se incorporo una macro para el envio de mensajes de error, warning e info.
Se mejoro y termino el servicio gamepad en el frontend.
Se testeo nuevamente el mediar la abteria y funciona correctamente
Se agrego un popup (modal) de introduccion al Frontend y uno a los botones inhabilitados

05 al 07 de Febrero
Correciones varias de cara a la presentacion del proyecto
Correciones y finalizacion del Informe finalizacion

07 de Febrero
Proyecto presentado y aprobado

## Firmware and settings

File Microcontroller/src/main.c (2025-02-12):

// #include "esp_log.h"
// #include "cyclops_core.h"
// #include "freertos/FreeRTOS.h"
// #include "freertos/task.h"
// #include "instruction_buffer.h"
// #include <stdio.h>
// #include <string.h>
// #include "mqtt_handler.h"
// static const char *TAG = "MAIN";

// void app_main(void)
// {
//         esp_err_t err = ESP_FAIL;
//         err = system_init();
//         if (err != ESP_OK)
//         {
//                 ESP_LOGE(TAG, "FATAL ERROR");
//         }
//         else
//         {
//                 err = createTasks();
//                 if (err != ESP_OK)
//                 {
//                         ESP_LOGE(TAG, "FATAL ERROR");
//                 }
//         }

//         ESP_LOGI(TAG, "ALL DONE");

//         TESTING SAVING INST
//         char inst1[] = "TESTING SEMDING MESSAGE";

//             while (1)
//         {
//                 err = sendInfoMesage(TAG,inst1);
//                 if (err != ESP_OK)
//                 {
//                         ESP_LOGW(TAG, "MESSAGE SEND FAIL: %s", esp_err_to_name(err));
//                 } else {
//                         ESP_LOGI(TAG,"MESSAGE SEND");
//                 }
//                 vTaskDelay(1500 / portTICK_PERIOD_MS);
//         }

// }

#include "esp_log.h"
#include "cyclops_core.h"
#include "freertos/FreeRTOS.h"
#include "freertos/task.h"
#include "mapping.h"
#include "battery.h"
#include "motors.h"
#include "mqtt_handler.h"

#include "esp_timer.h"
#include "heap_trace_helper.h"

static const char *TAG = "MAIN";

int app_main(void)
{
        esp_err_t err;

        heap_trace_start(HEAP_TRACE_ALL);

        ESP_LOGI(TAG, "Iniciando Sistemas...");
        err = system_init();
        if (err != ESP_OK)
        {
                ESP_LOGE(TAG, "Error Iniciando Sistemas:  %s", esp_err_to_name(err));
                return 1;
        }
        ESP_LOGI(TAG, "Sistemas Iniciado!");
        // GENERO PUNTO DE RETORNO

        ESP_LOGI(TAG, "Iniciando Tareas...");
        err = createTasks();
        if (err != ESP_OK)
        {
                ESP_LOGE(TAG, "Error Iniciando Tareas:  %s", esp_err_to_name(err));
                return 1;
        }
        ESP_LOGI(TAG, "Tareas Iniciadas!");
        /*
        uint64_t time_now = esp_timer_get_time();
        while(1){
                saveInstruction("Forward");
                vTaskDelay(50 / portTICK_PERIOD_MS);

                if ( (esp_timer_get_time() - time_now) > 120000000 ){
                        ESP_LOGI(TAG, "Pasó 1 minuto $$$$$$$$$$$$$$$$$$$$$$$$$$$$$$$$$$$$$$");
                        heap_caps_print_heap_info(MALLOC_CAP_8BIT);
                }
        }*/

        return 0;
}

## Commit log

2024-09-16 ESP32 Communication (Back to ESP)
2024-09-19 HTTP in ESP32
2024-09-26 I2C y Lidar
2024-09-28 agrego libreria para configurar al ESP32 como access point
2024-09-28 Modifico para que devuelva el tipo de error durante la inicializacion del AP
2024-09-29 Funcion para inicializar server
2024-09-29 Agrego servidor TCP que espera conexiones
2024-10-02 Se creó la carpeta "Build" dentro de Microchip. Esta se usa para configurar el CMAKE
2024-10-02 Actualización de la bitácora
2024-10-02 agrego libreria para gestionar el servidor http
2024-10-02 agrego handler para post de diferentes tipos de mensajes
2024-10-02 modifico test ya que wifi_init se realiza dentro del initialize
2024-10-02 arreglo error de nombre, y comento creacion de servidor tcp
    [main.c]
2024-10-03 Actualizo el .gitignore para que, coloquialmente, "no rompa más las bolas"
2024-10-04 Cree la librería de control de los motores
2024-10-04 Lisght test, not working well
    [main.c]
2024-10-14 Function fixed and Table Partition changed to large single app
    [main.c]
2024-10-21 Implementación de la librería de control del LiDAR
2024-10-25 Actualización de la librería
2024-10-26 Encontré un driver del sensor y lo subí a la librería de control
2024-10-28 Working for normal servo
2024-11-01 libreria para comunicacion con backend
2024-11-03 agrego tags en el envio de mensajes al backend
2024-11-03 sincronizo con Development y modifico publish para que reciba un json
2024-11-04 Hotfix de checkpoint
2024-11-04 Intento de arreglo
2024-11-05 Estuve haciendo avanzces con la librería y creo que puedo encontrarle la vuelta
2024-11-06 Se actualizó la librería de control y ahora mide distancias correctamente
    [main.c]
2024-11-06 Agrego inicializacion de interrupciones por hardware
2024-11-06 actualizo bitacora: agrego libreria de interrupciones
2024-11-09 Interruptions and debounce working
2024-11-09 modifico para que envie tag y tipo de mensaje (warning, error, info)
2024-11-09 modifico funcion para que se conecte, envie mensaje y se desconecte
2024-11-13 agrego monitor que muestre mensajesde testeo
2024-11-13 agrego componente en main para testear
2024-11-13 Agrego barra de desplazamiento
2024-11-13 modifico tamaño de componente
2024-11-14 funcion para agregar mensaje
2024-11-16 modifico para mostrar hora y tambien agrego identacion entre tipo y mensaje
2024-11-16 agrego mas mensajes de testeo
2024-11-17 Abstraction of I2C
2024-11-18 Ina219 i2c library
2024-11-20 Testeo para visualizar mapa con datos de prueba utilizando d3.js
2024-11-27 Modifico para que al hacer click sobre el mapa este se expanda o vuelva a su tamaño normal
2024-11-27 Modifico para que al hacer click sobre el mapa se expanda o vuelva a su tamaño original
2024-11-27 Modifico para que al hacer click se expanda o vuelva a su tamaño original
2024-11-29 Revert "Servo motor"
2024-11-29 Actualización local lista para sobrescribir remoto
2024-12-01 elimino componente map para hacer merge
2024-12-01 modifico para ver mapa y monitor, ademas de que cuando un componente se expanda el otro se contraiga
2024-12-02 INA219 working, wrong values read
    [main.c]
2024-12-02 Testing Lidar+servo
2024-12-03 Sidenav not expand when clicking in button
2024-12-03 Modifico para que cuando se expanda el mapa, se oculte el monitor
2024-12-03 Cambia de tamaño el mapa al expandirse/contraerse
2024-12-03 Modifico tamaño de monitor
2024-12-04 Modifico diseño de los botones
2024-12-04 agrego espacio entre grupo de botones
2024-12-04 Modifico boton de pausa, para ademas poder reanudar
2024-12-04 Modifico boton de velocidad
2024-12-04 Modifico boton para guardar mapeo
2024-12-05 I2C Doc
2024-12-07 modifico nombre de target
2024-12-08 Arreglo problema de bordes durante la captura del mapeo
2024-12-09 modifico tamaño de componentes
2024-12-09 agrego funcion para recibir mensajes del backend
2024-12-09 pausar mapeo de datos del back
2024-12-11 Motors Working
2024-12-11 pin fix
2024-12-11 rama de testeo de merge con main
2025-01-03 Testeo desplazamiento de auto en mapeo
2025-01-07 Chequeo de la sección de contról de los sensores
2025-01-08 Sensores operacionales en conjunto!
2025-01-12 agrego tarea para recibir instrucciones por http y almacenarlas en buffer
2025-01-12 agrego libreria de http
2025-01-15 correccion de errores en tarea para recibir instrucciones del backend
2025-01-20 agrego url del backend y verificacion de error al guardar instruccion
2025-01-22 Get working, pending fixing barrier
    [main.c]
2025-01-23 modifico para que reciba lista de puntos desde el backend
2025-01-24 EL merge no funcionó, así que volvemos para atrás
2025-01-24 Mergeo de las ramas Development y main-test
2025-01-28 agrego funciones necesarias para abortar (semaforos unicamente)
2025-01-28 envio de barrera
2025-01-31 renombro funcion + nueva rama para merge
2025-02-02 Cambios en el map, back y otros
2025-02-04 Memory leak solucionado y nueva librería de JSON implementada
    [main.c]
2025-02-04 Debug de esp log
2025-02-04 Flag de modo debugging agregado a la libreria de mapping
2025-02-04 sacar debug de mensajes de error
2025-02-04 Envio de errores y reiniciar lidar
2025-02-04 Battery status fixed
2025-02-05 mensajes de error, warning, info
2025-02-05 Bitacora corregida hasta el 23 de enero
2025-02-09 Some fixes in documentation and 3D STL added
    [PSSupport.STL]
2025-02-09 More Doc
    [PSSupport.STL]
2025-02-12 Instalacion y Confiracion del ESP32
2025-02-28 Fix 3D
    [BatteryCover.STL, Chasis.STL, ESP_HOLDERv2.STL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]
2025-04-15 Hotfix de los mensajes de error y un error de compilación en servo.c
